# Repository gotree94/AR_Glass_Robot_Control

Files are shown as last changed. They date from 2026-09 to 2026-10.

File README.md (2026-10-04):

# AR 안경 기반 협동로봇 Teleop/VLA 프로젝트

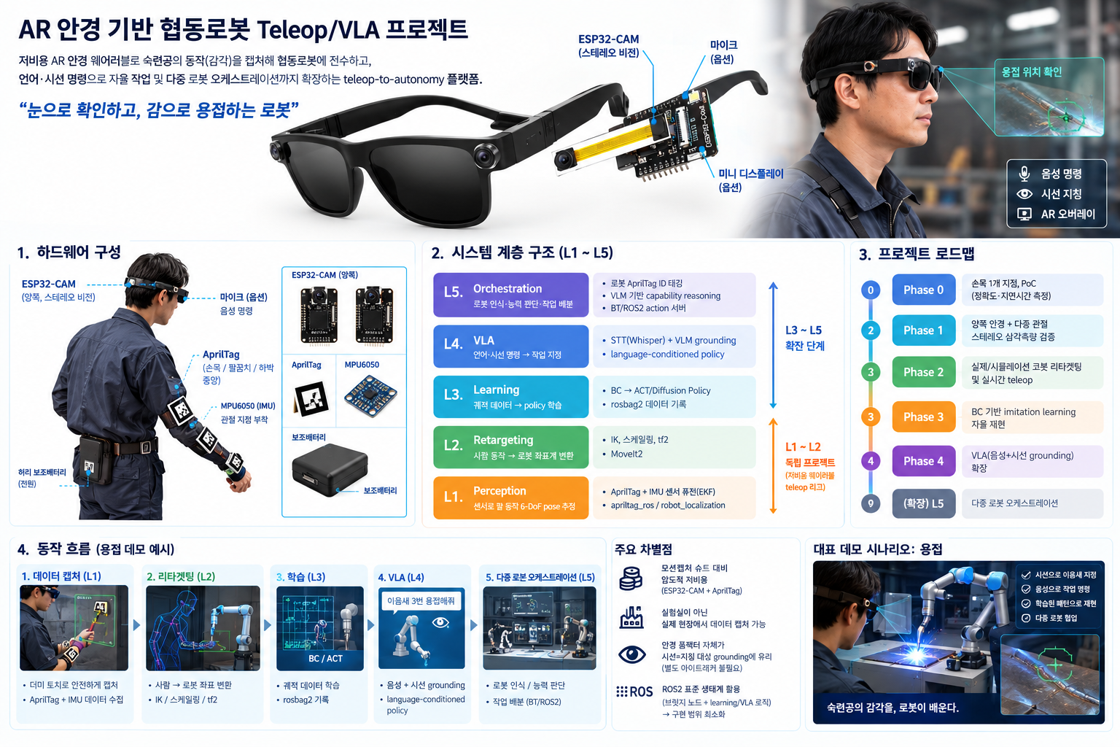
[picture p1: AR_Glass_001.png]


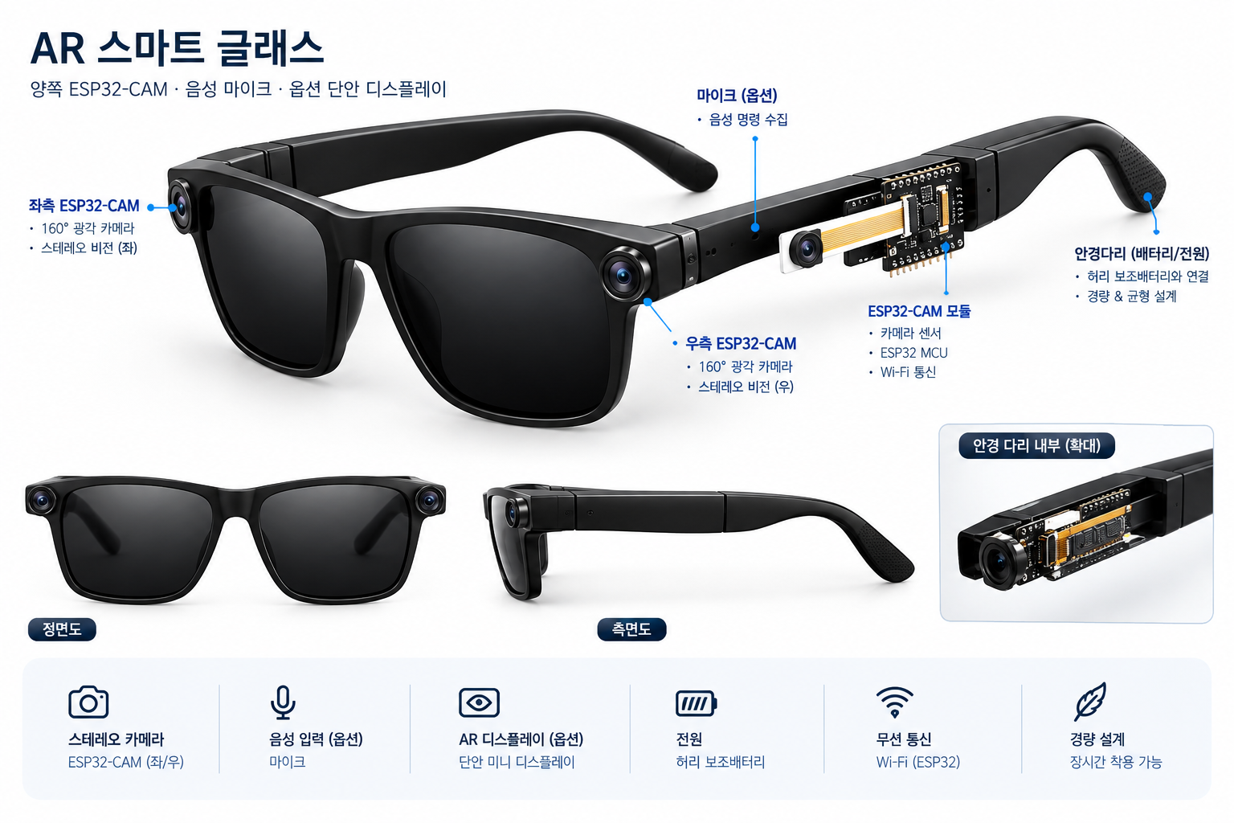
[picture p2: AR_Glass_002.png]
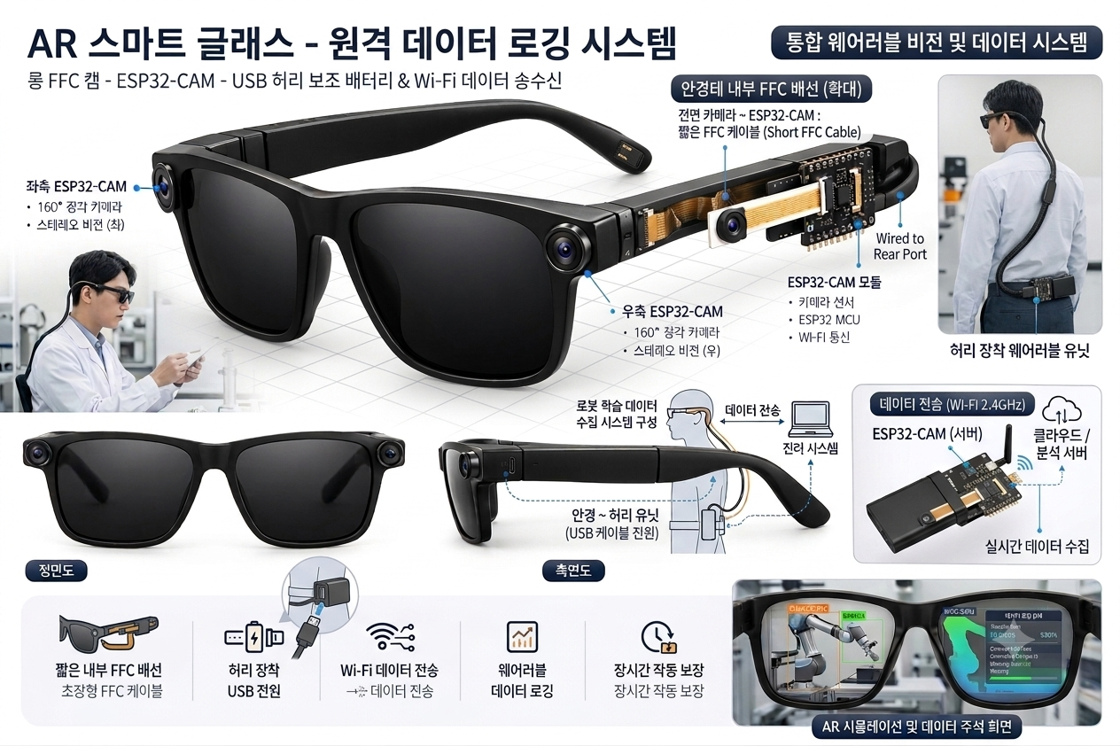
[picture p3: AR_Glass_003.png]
 

---

## 한 줄 컨셉
- 저비용 AR 안경 웨어러블로 숙련공의 동작(감각)을 캡처해 협동로봇에 전수하고,
- 언어·시선 명령으로 자율 작업 및 다중 로봇 오케스트레이션까지 확장하는 teleop-to-autonomy 플랫폼.

## 태그라인
- "눈으로 확인하고, 감으로 용접하는 로봇"

## 하드웨어 구성
- 안경 양쪽 ESP32-CAM (스테레오 비전) + 허리 보조배터리 전원
- 손목 / 팔꿈치(또는 하박 중앙)에 AprilTag 부착
- 관절 지점에 MPU6050(IMU) 추가 → 비전-IMU 센서 퓨전으로 occlusion 보완, 샘플링레이트 향상
- (확장) 안경 마이크 → 음성 명령, (확장) 단안 미니 디스플레이 → AR 오버레이

---
## 1. Tag Glove (70mm * 70mm)

### Version 0.1

   * 제작시 한쪽이 부러지는 문제와, 착용성이 좋지 않음.

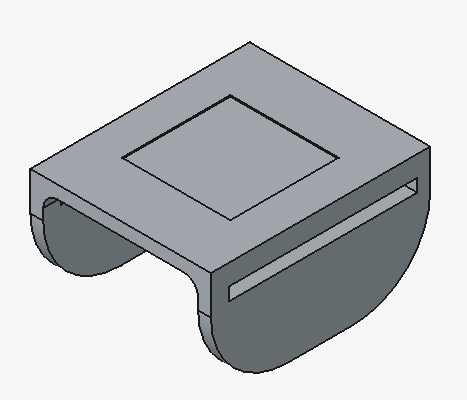
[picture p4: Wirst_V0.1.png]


### Version 0.2

   * 오른쪽과 왼쪽으로 분리 : 착용의 편의성 개선

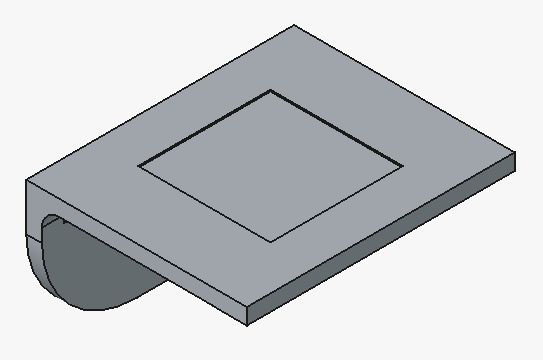
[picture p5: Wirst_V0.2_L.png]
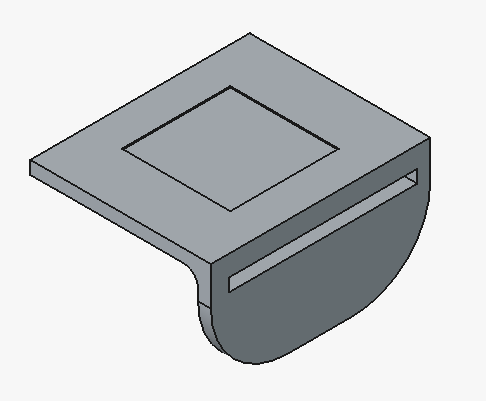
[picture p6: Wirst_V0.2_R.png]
 

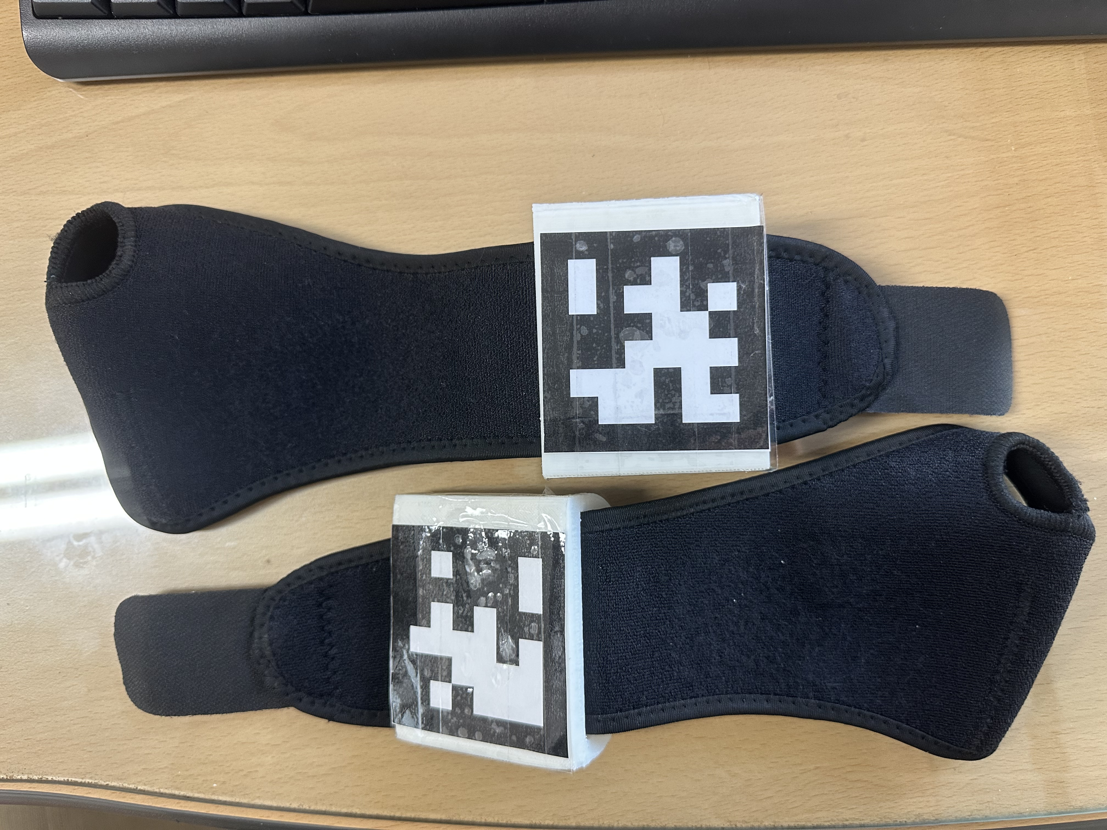
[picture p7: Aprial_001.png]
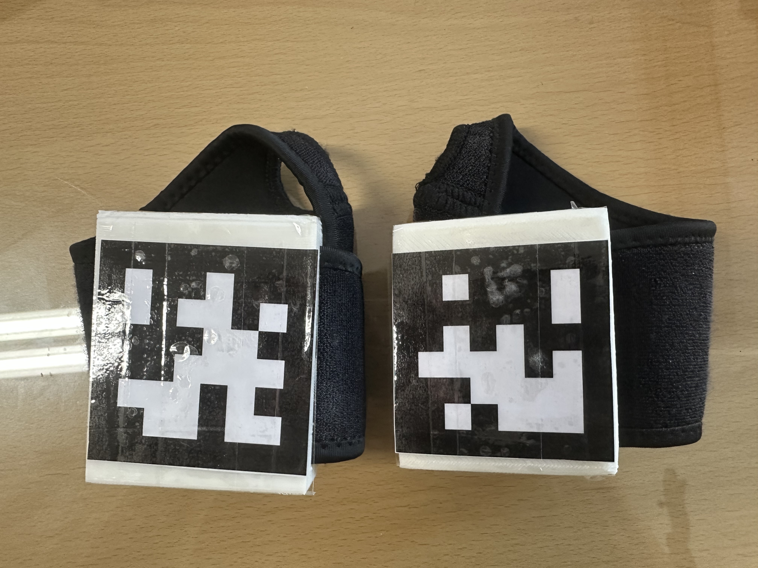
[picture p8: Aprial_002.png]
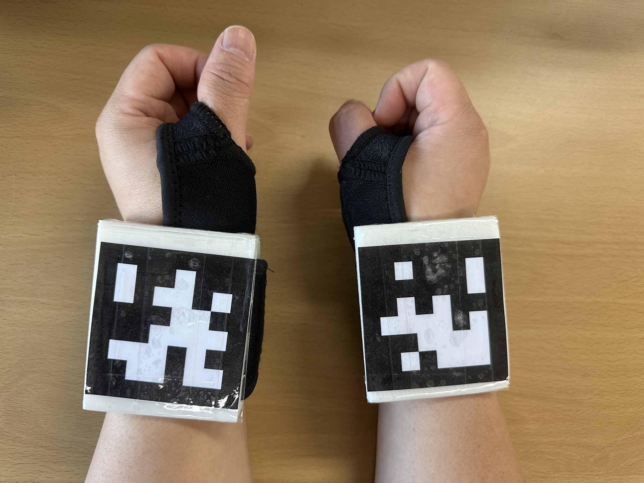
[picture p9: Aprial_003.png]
  

---

## 2. AR Glass

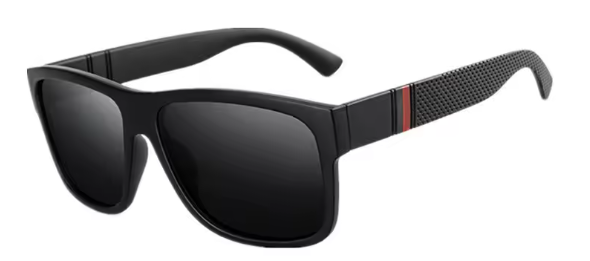
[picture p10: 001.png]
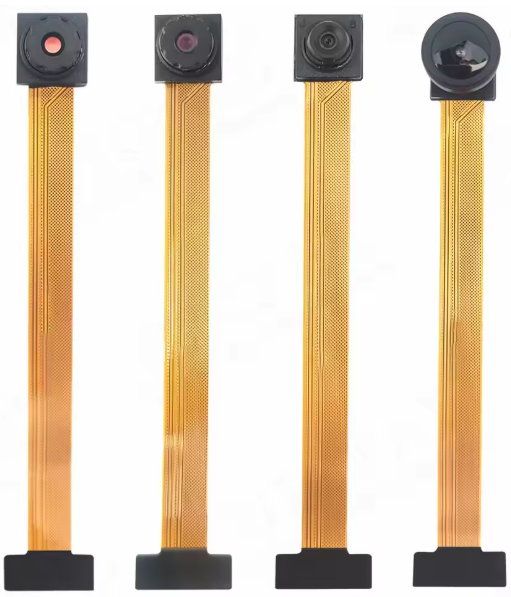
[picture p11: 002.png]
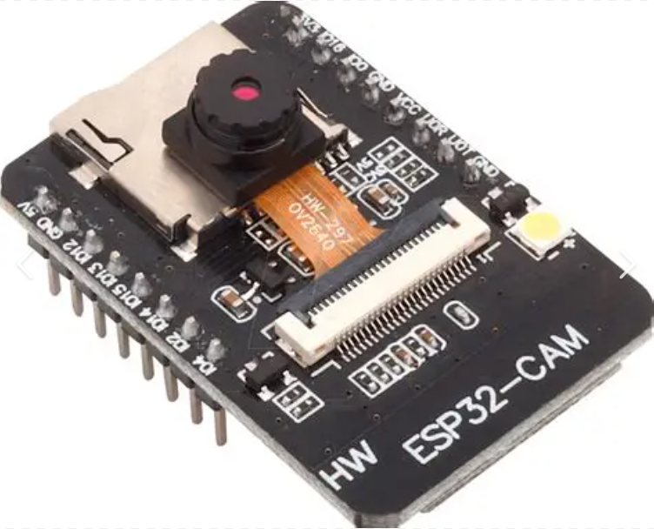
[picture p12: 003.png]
  

### 1. CAM Test

* 오른쪽 왼쪽 카메라 테스트

   * 교실 : http://192.168.0.137/ , http://192.168.0.69/
   * 연구실 : http://192.168.1.5/ , http://192.168.1.7/

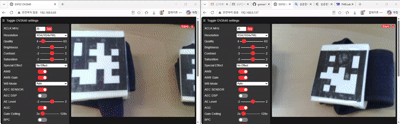
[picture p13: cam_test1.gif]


### 2. CAM Holder Design & Assemble.

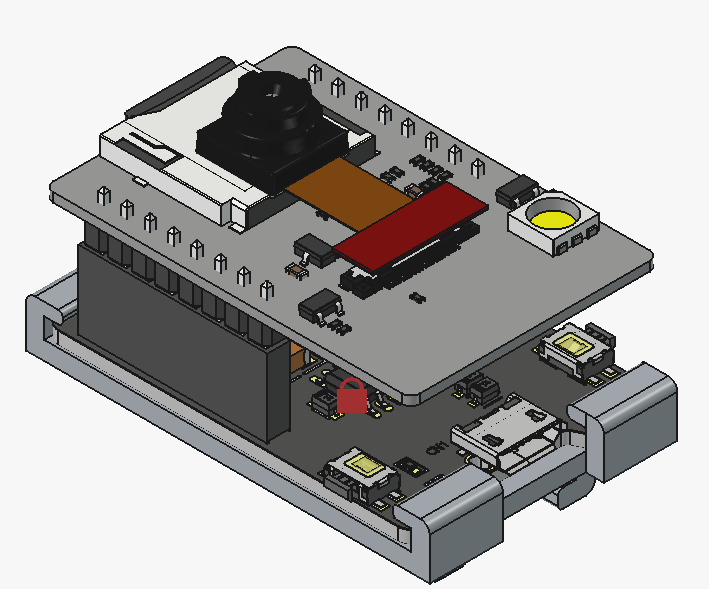
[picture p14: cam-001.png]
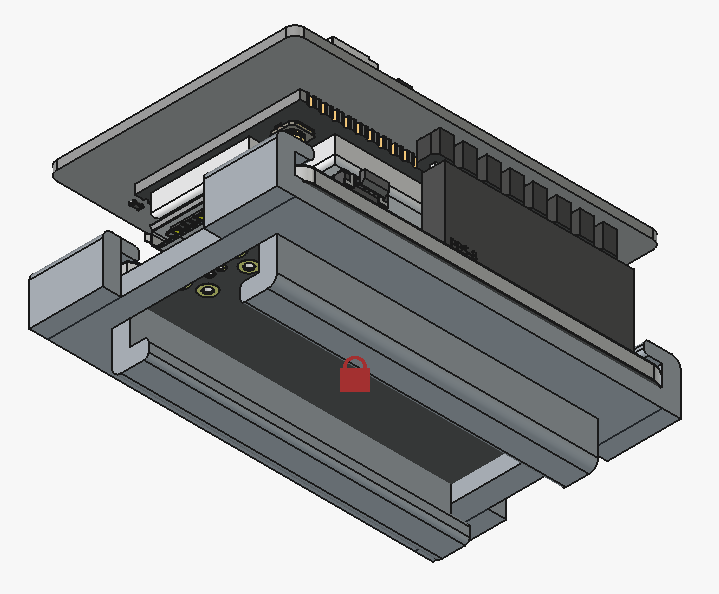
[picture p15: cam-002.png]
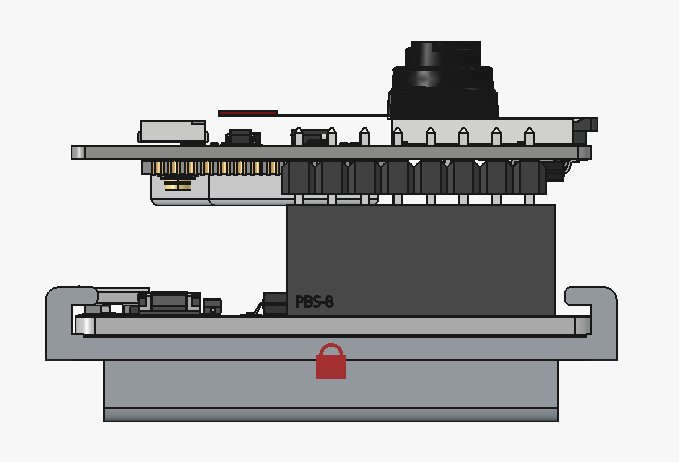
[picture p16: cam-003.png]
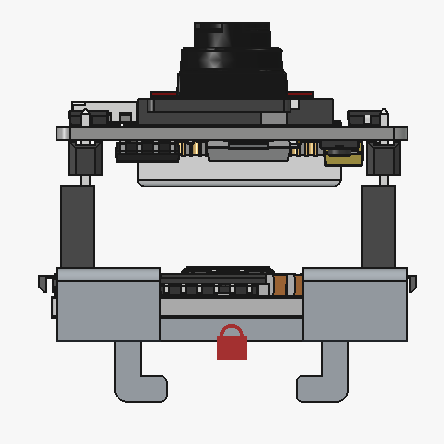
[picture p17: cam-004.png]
   

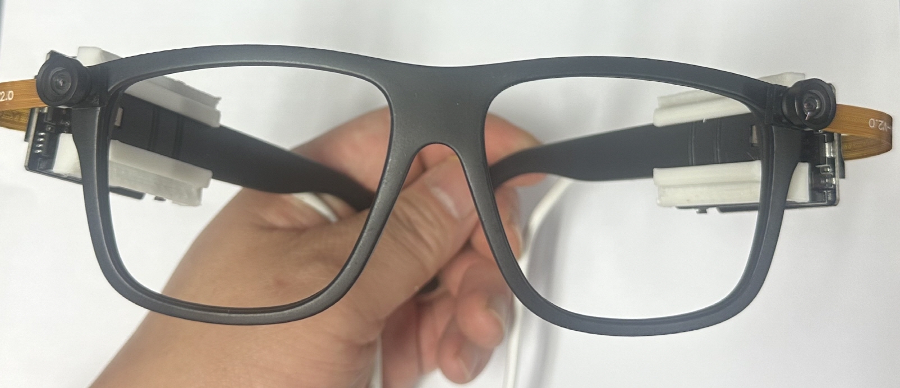
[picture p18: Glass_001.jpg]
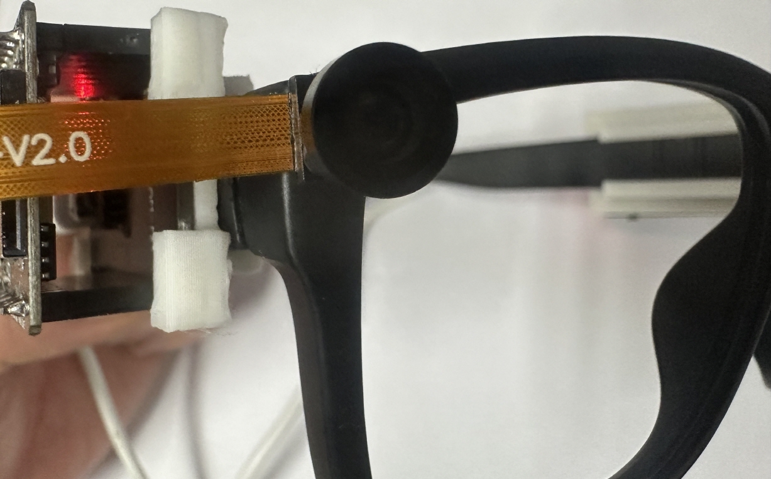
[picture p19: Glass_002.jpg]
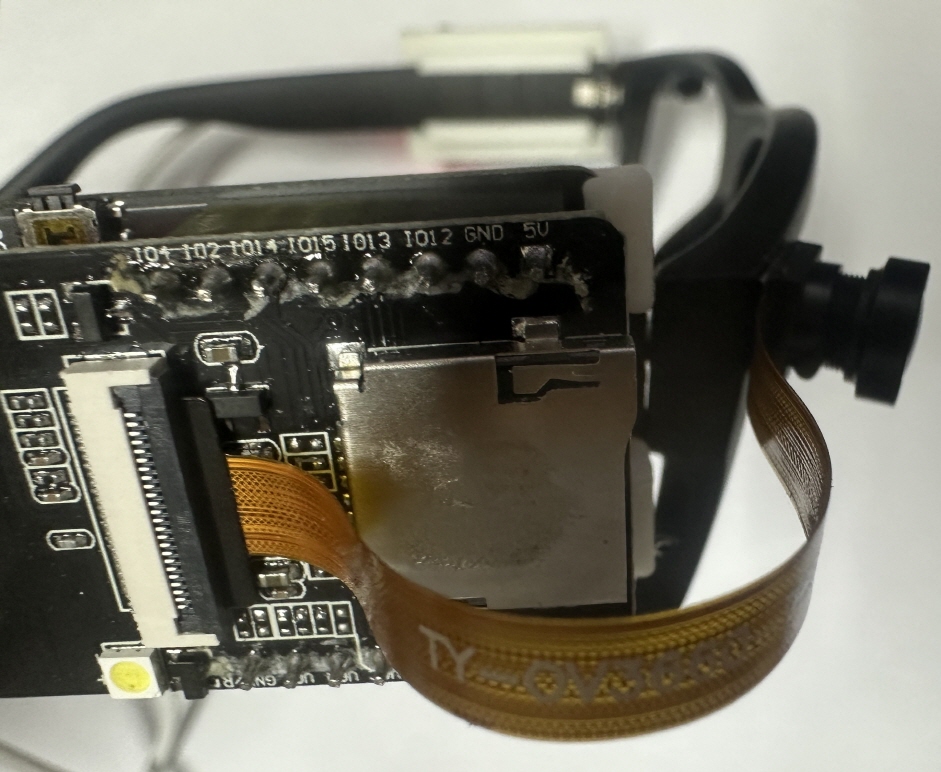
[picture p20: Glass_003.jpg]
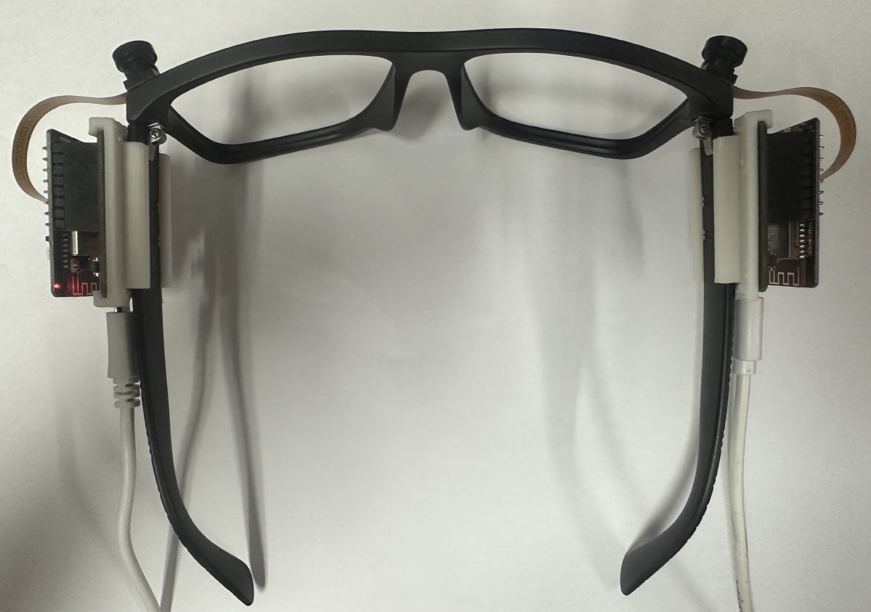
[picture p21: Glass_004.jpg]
   

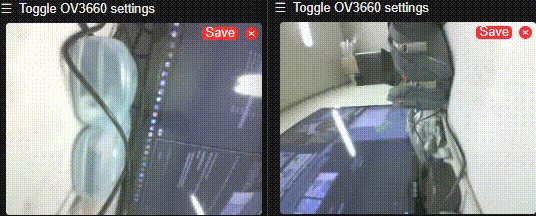
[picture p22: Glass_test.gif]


---

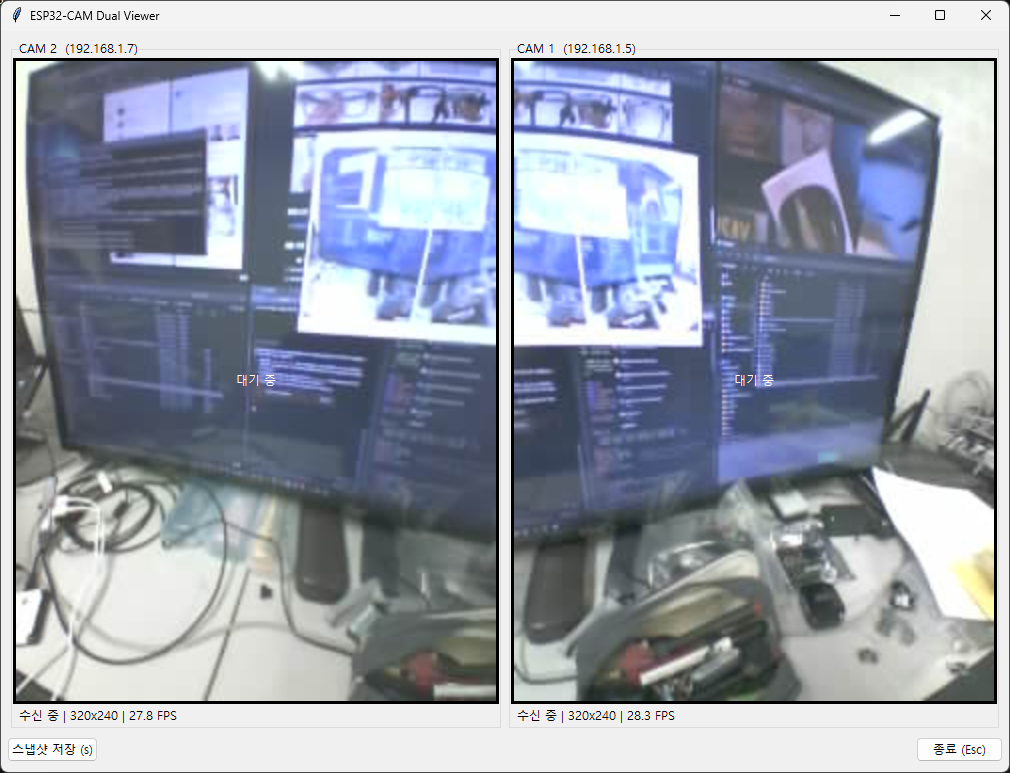
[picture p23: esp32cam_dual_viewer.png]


[esp32cam_dual_viewer.py](esp32cam_dual_viewer.py)

```python
#!/usr/bin/env python3
"""
ESP32-CAM 2대 MJPEG 스트림을 하나의 Tkinter UI에 표시

설치:  pip install requests pillow
실행:  python esp32cam_dual_viewer.py

- 스트림 주소: http://<IP>:81/stream  (CameraWebServer 기본)
- 카메라마다 별도 스레드로 수신, 끊기면 자동 재연결
- 's' 키 또는 [스냅샷 저장] 버튼: 현재 프레임을 snapshots/ 폴더에 저장
"""

import io
import os
import threading
import time
import tkinter as tk
from datetime import datetime
from tkinter import ttk

import requests
from PIL import Image, ImageTk

# ------------------------------------------------------------------ 설정
CAMERAS = [
    # rotate: 시계 방향이 +, 반시계 방향이 - (단위: 도, 90 단위만 지원)
    {"name": "CAM 2", "host": "192.168.1.7", "rotate": -90},   # 왼쪽
    {"name": "CAM 1", "host": "192.168.1.5", "rotate": 90},    # 오른쪽
]
STREAM_PORT = 81
STREAM_PATH = "/stream"
DISPLAY_SIZE = (480, 640)      # 카메라당 표시 영역 (가로, 세로) - 90도 회전하면 세로가 길어짐
UI_REFRESH_MS = 30             # UI 갱신 주기
STALE_SEC = 3.0                # 이 시간 동안 프레임 없으면 '끊김' 표시
SNAPSHOT_DIR = "snapshots"
# ----------------------------------------------------------------------

def rotate_img(img, deg):
    """시계 방향 +deg 회전 (PIL의 rotate는 반시계가 +이므로 부호 반전)"""
    deg %= 360
    if deg == 0:
        return img
    return img.rotate(-deg, expand=True)

def fit_to_box(img, size):
    """비율을 유지한 채 size 안에 맞추고 나머지는 검은색으로 채움"""
    scale = min(size[0] / img.width, size[1] / img.height)
    new_w, new_h = max(1, int(img.width * scale)), max(1, int(img.height * scale))
    img = img.resize((new_w, new_h), Image.BILINEAR)
    canvas = Image.new("RGB", size, "black")
    canvas.paste(img, ((size[0] - new_w) // 2, (size[1] - new_h) // 2))
    return canvas

class CamWorker(threading.Thread):
    """MJPEG 스트림을 받아 최신 프레임(PIL.Image)만 보관하는 스레드"""

    def __init__(self, name, host):
        super().__init__(daemon=True)
        self.name = name
        self.url = f"http://{host}:{STREAM_PORT}{STREAM_PATH}"
        self._stop_evt = threading.Event()
        self._lock = threading.Lock()
        self._frame = None
        self._frame_time = 0.0
        self._fps = 0.0
        self.status = "연결 중..."

    # ---- 외부에서 호출
    def get_frame(self):
        with self._lock:
            return self._frame, self._frame_time, self._fps

    def stop(self):
        self._stop_evt.set()

    # ---- 스레드 본체
    def run(self):
        while not self._stop_evt.is_set():
            try:
                self.status = "연결 중..."
                with requests.get(self.url, stream=True, timeout=(3, 5)) as resp:
                    resp.raise_for_status()
                    self.status = "수신 중"
                    self._read_mjpeg(resp)
            except Exception as e:  # 네트워크 오류 등
                self.status = f"오류: {type(e).__name__}"
            # 재연결 전 잠깐 대기
            self._stop_evt.wait(1.5)

    def _read_mjpeg(self, resp):
        buf = b""
        t0, n = time.time(), 0
        for chunk in resp.iter_content(chunk_size=1024):
            if self._stop_evt.is_set():
                return
            if not chunk:
                continue
            buf += chunk
            while True:
                soi = buf.find(b"\xff\xd8")          # JPEG 시작
                if soi == -1:
                    buf = buf[-1:]
                    break
                eoi = buf.find(b"\xff\xd9", soi + 2)  # JPEG 끝
                if eoi == -1:
                    buf = buf[soi:]
                    break
                jpg, buf = buf[soi:eoi + 2], buf[eoi + 2:]
                try:
                    img = Image.open(io.BytesIO(jpg))
                    img.load()
                except Exception:
                    continue  # 깨진 프레임은 버림
                n += 1
                now = time.time()
                with self._lock:
                    self._frame = img
                    self._frame_time = now
                    if now - t0 >= 1.0:
                        self._fps = n / (now - t0)
                        t0, n = now, 0

class App:
    def __init__(self, root):
        self.root = root
        root.title("ESP32-CAM Dual Viewer")
        root.protocol("WM_DELETE_WINDOW", self.on_close)
        root.bind("<Key-s>", lambda e: self.save_snapshots())
        root.bind("<Escape>", lambda e: self.on_close())

        self.workers = [CamWorker(c["name"], c["host"]) for c in CAMERAS]
        self.labels, self.info_vars, self.photos = [], [], [None] * len(CAMERAS)

        frame = ttk.Frame(root, padding=6)
        frame.pack(fill="both", expand=True)

        for i, c in enumerate(CAMERAS):
            box = ttk.LabelFrame(frame, text=f"{c['name']}  ({c['host']})")
            box.grid(row=0, column=i, padx=4, pady=4)
            lbl = tk.Label(box, width=DISPLAY_SIZE[0], height=DISPLAY_SIZE[1],
                           bg="black", fg="white", text="대기 중",
                           compound="center")
            # Label의 width/height는 이미지가 없을 때 '문자 단위'이므로 픽셀 지정용 빈 이미지 사용
            blank = ImageTk.PhotoImage(Image.new("RGB", DISPLAY_SIZE, "black"))
            lbl.configure(image=blank, width=DISPLAY_SIZE[0], height=DISPLAY_SIZE[1])
            lbl.image = blank
            lbl.pack()
            var = tk.StringVar(value="-")
            ttk.Label(box, textvariable=var).pack(anchor="w", padx=4, pady=2)
            self.labels.append(lbl)
            self.info_vars.append(var)

        bar = ttk.Frame(frame)
        bar.grid(row=1, column=0, columnspan=len(CAMERAS), sticky="ew", pady=4)
        ttk.Button(bar, text="스냅샷 저장 (s)", command=self.save_snapshots).pack(side="left")
        ttk.Button(bar, text="종료 (Esc)", command=self.on_close).pack(side="right")

        for w in self.workers:
            w.start()
        self.update_ui()

    def update_ui(self):
        now = time.time()
        for i, w in enumerate(self.workers):
            img, ts, fps = w.get_frame()
            alive = img is not None and (now - ts) < STALE_SEC
            if alive:
                rot = rotate_img(img.convert("RGB"), CAMERAS[i].get("rotate", 0))
                disp = fit_to_box(rot, DISPLAY_SIZE)
                self.photos[i] = ImageTk.PhotoImage(disp)
                self.labels[i].configure(image=self.photos[i])
                self.labels[i].image = self.photos[i]
                self.info_vars[i].set(f"{w.status} | {img.size[0]}x{img.size[1]} | {fps:.1f} FPS")
            else:
                self.info_vars[i].set(f"끊김 - {w.status}")
        self.root.after(UI_REFRESH_MS, self.update_ui)

    def save_snapshots(self):
        os.makedirs(SNAPSHOT_DIR, exist_ok=True)
        stamp = datetime.now().strftime("%Y%m%d_%H%M%S")
        for c, w in zip(CAMERAS, self.workers):
            img, _, _ = w.get_frame()
            if img is not None:
                path = os.path.join(SNAPSHOT_DIR, f"{c['name'].replace(' ', '')}_{stamp}.jpg")
                rotate_img(img.convert("RGB"), c.get("rotate", 0)).save(path, quality=95)
                print("saved:", path)

    def on_close(self):
        for w in self.workers:
            w.stop()
        self.root.destroy()

if __name__ == "__main__":
    root = tk.Tk()
    App(root)
    root.mainloop()
```

### AprilTag_6개 인식 확인



* ESP32-CAM Dual Viewer + AprilTag 인식
   * ESP32-CAM 2대의 MJPEG 스트림을 하나의 창에 표시하고, AprilTag(36h11, ID 0~5)를 인식해 거리와 위치를 보여줍니다.

#### 설치

```bash
pip install requests pillow numpy "opencv-python>=4.7"
```

#### 실행

```bash
python esp32cam_dual_viewer.py
```

#### 동작

- 회전을 적용한 화면에서 태그를 찾아 **녹색 테두리, 좌표축, `ID번호 거리mm`**를 화면에 그립니다.
- 각 카메라 화면 아래에 검출된 태그의 **이름, 거리, 카메라 기준 xyz(mm)**가 표시됩니다. 이름은 태그 이미지의 라벨을 그대로 사용합니다.
- 태그 크기는 **68mm**(검은 테두리 바깥 기준)로 `TAG_SIZE_MM`에 설정되어 있습니다.
- **ID 0~5 외의 태그는 오검출 방지를 위해 무시**합니다.
- 하단의 **"AprilTag 인식"** 체크박스로 인식을 켜고 끌 수 있습니다.
- 스냅샷(`s` 키)은 표시가 없는 깨끗한 프레임으로 `snapshots/`에 저장됩니다.
- 새 프레임이 들어올 때만 검출하므로 UI가 불필요하게 바쁘지 않습니다.

##### 태그 ID

| ID | 이름 | ID | 이름 |
|----|---|----|---|
| 0 | `RIGHT_1_THUMB_INDEX` | 3 | `LEFT_1_THUMB_INDEX` |
| 1 | `RIGHT_2_HAND` | 4 | `LEFT_2_HAND` |
| 2 | `RIGHT_3_FOREARM` | 5 | `LEFT_3_FOREARM` |

#### 거리 정확도 보정

- ESP32-CAM은 카메라 보정(캘리브레이션) 값이 없어서, 거리와 xyz는 `CAMERAS`의 **`fov`**(회전 전 원본 영상의 가로 화각, 기본 65°)로 추정한 값입니다.
- 태그를 카메라에서 정확히 **300mm** 떨어뜨려 놓고, 표시되는 거리가 그와 맞을 때까지 `fov`를 조정하세요.
  - 표시 거리가 실제보다 **크면** `fov`를 **키웁니다**.
  - 표시 거리가 실제보다 **작으면** `fov`를 **줄입니다**.
- 광각 렌즈 모듈은 화각이 100° 이상일 수 있습니다. 이 경우 렌즈 왜곡 때문에 화면 가장자리에서 오차가 커집니다.
- 정밀한 위치가 필요하면 체커보드로 카메라 보정을 해서 카메라 행렬과 왜곡 계수를 코드에 넣는 방식으로 확장할 수 있습니다.

#### 인식률을 높이는 팁

- 태그 주변에 **흰 여백**을 태그 한 칸(약 8mm) 이상 확보하세요.
- 해상도는 **VGA(640x480) 이상**이 좋습니다. QVGA에서는 인식 가능 거리가 크게 줄어듭니다.
- 화면에서 태그 한 변이 **약 30px 이상**이어야 인식되고, 안정적으로는 **50px 이상**이 좋습니다.

##### 인식 가능 거리 (68mm 태그, VGA, 화각 65° 기준)

| 태그 한 변(px) | 거리 |
|---|---|
| 114px | 약 30cm |
| 50px | 약 70cm |
| 30px | 약 110cm (인식 한계) |

화각이 넓은 렌즈일수록 같은 거리에서 태그가 작게 보이므로 인식 가능 거리는 짧아집니다.

#### 참고

- 스트림 주소는 `http://<IP>:81/stream`입니다. 브라우저에서 스트림을 켜 둔 상태면 연결되지 않으므로 탭을 닫아 주세요.
- 회전은 `CAMERAS`의 `rotate`(시계 방향 +, 반시계 방향 -, 90 단위)로 설정합니다.

```python
#!/usr/bin/env python3
"""
ESP32-CAM 2대 MJPEG 스트림을 하나의 Tkinter UI에 표시 + AprilTag(36h11) 인식

설치:  pip install requests pillow numpy "opencv-python>=4.7"
실행:  python esp32cam_dual_viewer.py

- 스트림 주소: http://<IP>:81/stream  (CameraWebServer 기본)
- 카메라마다 별도 스레드로 수신, 끊기면 자동 재연결
- AprilTag 36h11, ID 0~5, 실제 크기 68mm (검은 테두리 바깥쪽 기준)
- 's' 키 또는 [스냅샷 저장] 버튼: 회전 적용된 원본 프레임을 snapshots/ 에 저장
"""

import io
import math
import os
import threading
import time
import tkinter as tk
from datetime import datetime
from tkinter import ttk

import cv2
import numpy as np
import requests
from PIL import Image, ImageTk

# ------------------------------------------------------------------ 설정
CAMERAS = [
    # rotate: 시계 방향이 +, 반시계 방향이 - (단위: 도, 90 단위만 지원)
    # fov   : 회전 전 원본 영상의 '가로' 화각(도). 거리 계산용 추정값 (아래 설명 참고)
    {"name": "CAM 2", "host": "192.168.1.7", "rotate": -90, "fov": 65.0},   # 왼쪽
    {"name": "CAM 1", "host": "192.168.1.5", "rotate": 90,  "fov": 65.0},   # 오른쪽
]
STREAM_PORT = 81
STREAM_PATH = "/stream"
DISPLAY_SIZE = (480, 640)      # 카메라당 표시 영역 (가로, 세로)
UI_REFRESH_MS = 30             # UI 갱신 주기
STALE_SEC = 3.0                # 이 시간 동안 프레임 없으면 '끊김' 표시
SNAPSHOT_DIR = "snapshots"

# --- AprilTag 설정
TAG_DICT = cv2.aruco.DICT_APRILTAG_36h11
TAG_SIZE_MM = 68.0             # 검은 테두리 바깥 한 변의 실제 길이
TAG_NAMES = {
    0: "RIGHT_1_THUMB_INDEX",
    1: "RIGHT_2_HAND",
    2: "RIGHT_3_FOREARM",
    3: "LEFT_1_THUMB_INDEX",
    4: "LEFT_2_HAND",
    5: "LEFT_3_FOREARM",
}
# ----------------------------------------------------------------------

def rotate_img(img, deg):
    """시계 방향 +deg 회전 (PIL의 rotate는 반시계가 +이므로 부호 반전)"""
    deg %= 360
    if deg == 0:
        return img
    return img.rotate(-deg, expand=True)

def fit_to_box(img, size):
    """비율을 유지한 채 size 안에 맞추고 나머지는 검은색으로 채움"""
    scale = min(size[0] / img.width, size[1] / img.height)
    new_w, new_h = max(1, int(img.width * scale)), max(1, int(img.height * scale))
    img = img.resize((new_w, new_h), Image.BILINEAR)
    canvas = Image.new("RGB", size, "black")
    canvas.paste(img, ((size[0] - new_w) // 2, (size[1] - new_h) // 2))
    return canvas

class TagDetector:
    """AprilTag 36h11 검출 + 68mm 기준 자세(위치) 추정 + 화면 표시"""

    def __init__(self):
        dictionary = cv2.aruco.getPredefinedDictionary(TAG_DICT)
        params = cv2.aruco.DetectorParameters()
        params.cornerRefinementMethod = cv2.aruco.CORNER_REFINE_SUBPIX
        self.detector = cv2.aruco.ArucoDetector(dictionary, params)
        h = TAG_SIZE_MM / 2.0
        # 코너 순서: 좌상, 우상, 우하, 좌하 (태그 중심이 원점, 단위 mm)
        self.obj_pts = np.array([[-h, h, 0], [h, h, 0], [h, -h, 0], [-h, -h, 0]],
                                dtype=np.float64)

    def process(self, rgb, focal_px):
        """rgb(ndarray)에 검출 결과를 직접 그리고, 검출 리스트를 반환"""
        gray = cv2.cvtColor(rgb, cv2.COLOR_RGB2GRAY)
        corners, ids, _ = self.detector.detectMarkers(gray)
        results = []
        if ids is None:
            return results

        hgt, wid = gray.shape
        K = np.array([[focal_px, 0, wid / 2.0],
                      [0, focal_px, hgt / 2.0],
                      [0, 0, 1]], dtype=np.float64)
        dist = np.zeros(5)

        for c, tag_id in zip(corners, ids.flatten()):
            tag_id = int(tag_id)
            if tag_id not in TAG_NAMES:      # ID 0~5 외에는 무시
                continue
            pts = c.reshape(4, 2).astype(np.float64)
            ok, rvec, tvec = cv2.solvePnP(self.obj_pts, pts, K, dist,
                                          flags=cv2.SOLVEPNP_IPPE_SQUARE)
            if not ok:
                continue
            x, y, z = tvec.flatten()
            d = float(np.linalg.norm(tvec))
            results.append({"id": tag_id, "name": TAG_NAMES[tag_id],
                            "x": x, "y": y, "z": z, "dist": d})

            # ---- 그리기
            poly = pts.astype(np.int32).reshape(-1, 1, 2)
            cv2.polylines(rgb, [poly], True, (0, 255, 0), 2)
            cv2.circle(rgb, tuple(poly[0, 0]), 5, (255, 0, 0), -1)   # 좌상단 코너 표시
            cv2.drawFrameAxes(rgb, K, dist, rvec, tvec, TAG_SIZE_MM * 0.6, 2)
            label = f"ID{tag_id} {d:.0f}mm"
            org = (int(pts[:, 0].min()), max(15, int(pts[:, 1].min()) - 8))
            cv2.putText(rgb, label, org, cv2.FONT_HERSHEY_SIMPLEX, 0.55, (0, 0, 0), 3, cv2.LINE_AA)
            cv2.putText(rgb, label, org, cv2.FONT_HERSHEY_SIMPLEX, 0.55, (255, 255, 0), 1, cv2.LINE_AA)

        results.sort(key=lambda r: r["id"])
        return results

class CamWorker(threading.Thread):
    """MJPEG 스트림을 받아 최신 프레임(PIL.Image)만 보관하는 스레드"""

    def __init__(self, name, host):
        super().__init__(daemon=True)
        self.name = name
        self.url = f"http://{host}:{STREAM_PORT}{STREAM_PATH}"
        self._stop_evt = threading.Event()
        self._lock = threading.Lock()
        self._frame = None
        self._frame_time = 0.0
        self._fps = 0.0
        self.status = "연결 중..."

    # ---- 외부에서 호출
    def get_frame(self):
        with self._lock:
            return self._frame, self._frame_time, self._fps

    def stop(self):
        self._stop_evt.set()

    # ---- 스레드 본체
    def run(self):
        while not self._stop_evt.is_set():
            try:
                self.status = "연결 중..."
                with requests.get(self.url, stream=True, timeout=(3, 5)) as resp:
                    resp.raise_for_status()
                    self.status = "수신 중"
                    self._read_mjpeg(resp)
            except Exception as e:  # 네트워크 오류 등
                self.status = f"오류: {type(e).__name__}"
            # 재연결 전 잠깐 대기
            self._stop_evt.wait(1.5)

    def _read_mjpeg(self, resp):
        buf = b""
        t0, n = time.time(), 0
        for chunk in resp.iter_content(chunk_size=1024):
            if self._stop_evt.is_set():
                return
            if not chunk:
                continue
            buf += chunk
            while True:
                soi = buf.find(b"\xff\xd8")          # JPEG 시작
                if soi == -1:
                    buf = buf[-1:]
                    break
                eoi = buf.find(b"\xff\xd9", soi + 2)  # JPEG 끝
                if eoi == -1:
                    buf = buf[soi:]
                    break
                jpg, buf = buf[soi:eoi + 2], buf[eoi + 2:]
                try:
                    img = Image.open(io.BytesIO(jpg))
                    img.load()
                except Exception:
                    continue  # 깨진 프레임은 버림
                n += 1
                now = time.time()
                with self._lock:
                    self._frame = img
                    self._frame_time = now
                    if now - t0 >= 1.0:
                        self._fps = n / (now - t0)
                        t0, n = now, 0

class App:
    def __init__(self, root):
        self.root = root
        root.title("ESP32-CAM Dual Viewer + AprilTag")
        root.protocol("WM_DELETE_WINDOW", self.on_close)
        root.bind("<Key-s>", lambda e: self.save_snapshots())
        root.bind("<Escape>", lambda e: self.on_close())

        n = len(CAMERAS)
        self.detector = TagDetector()
        self.workers = [CamWorker(c["name"], c["host"]) for c in CAMERAS]
        self.labels, self.info_vars, self.tag_vars = [], [], []
        self.photos = [None] * n
        self.raw_rot = [None] * n      # 스냅샷용 (회전만 적용, 표시 없음)
        self.last_ts = [0.0] * n
        self.detect_on = tk.BooleanVar(value=True)

        frame = ttk.Frame(root, padding=6)
        frame.pack(fill="both", expand=True)

        for i, c in enumerate(CAMERAS):
            box = ttk.LabelFrame(frame, text=f"{c['name']}  ({c['host']})")
            box.grid(row=0, column=i, padx=4, pady=4)
            blank = ImageTk.PhotoImage(Image.new("RGB", DISPLAY_SIZE, "black"))
            lbl = tk.Label(box, image=blank, bg="black")
            lbl.image = blank
            lbl.pack()
            info = tk.StringVar(value="-")
            ttk.Label(box, textvariable=info).pack(anchor="w", padx=4, pady=(2, 0))
            tags = tk.StringVar(value="")
            tk.Label(box, textvariable=tags, font=("Consolas", 9), justify="left",
                     anchor="nw", height=6, width=62).pack(anchor="w", padx=4, pady=(0, 2))
            self.labels.append(lbl)
            self.info_vars.append(info)
            self.tag_vars.append(tags)

        bar = ttk.Frame(frame)
        bar.grid(row=1, column=0, columnspan=n, sticky="ew", pady=4)
        ttk.Button(bar, text="스냅샷 저장 (s)", command=self.save_snapshots).pack(side="left")
        ttk.Checkbutton(bar, text="AprilTag 인식", variable=self.detect_on).pack(side="left", padx=12)
        ttk.Button(bar, text="종료 (Esc)", command=self.on_close).pack(side="right")

        for w in self.workers:
            w.start()
        self.update_ui()

    def process_frame(self, i, img):
        """새 프레임 1장 처리: 회전 -> 태그 인식 -> 표시용 이미지 반환"""
        cam = CAMERAS[i]
        fov = cam.get("fov", 65.0)
        # 초점거리(px): 원본 가로 화각 기준. 회전해도 초점거리는 변하지 않음
        focal = (img.width / 2.0) / math.tan(math.radians(fov) / 2.0)

        raw = rotate_img(img.convert("RGB"), cam.get("rotate", 0))
        self.raw_rot[i] = raw
        arr = np.array(raw)                       # 복사본 (여기에만 그림)
        tags = self.detector.process(arr, focal) if self.detect_on.get() else []

        lines = [f"ID{t['id']} {t['name']:<19} {t['dist']:6.0f}mm  "
                 f"xyz=({t['x']:.0f},{t['y']:.0f},{t['z']:.0f})" for t in tags]
        self.tag_vars[i].set("\n".join(lines))
        return fit_to_box(Image.fromarray(arr), DISPLAY_SIZE), len(tags)

    def update_ui(self):
        now = time.time()
        for i, w in enumerate(self.workers):
            img, ts, fps = w.get_frame()
            alive = img is not None and (now - ts) < STALE_SEC
            if not alive:
                self.info_vars[i].set(f"끊김 - {w.status}")
                self.tag_vars[i].set("")
                continue
            if ts != self.last_ts[i]:             # 새 프레임일 때만 처리
                self.last_ts[i] = ts
                disp, n_tags = self.process_frame(i, img)
                self.photos[i] = ImageTk.PhotoImage(disp)
                self.labels[i].configure(image=self.photos[i])
                self.labels[i].image = self.photos[i]
                self.info_vars[i].set(
                    f"{w.status} | {img.size[0]}x{img.size[1]} | {fps:.1f} FPS | 태그 {n_tags}개")
        self.root.after(UI_REFRESH_MS, self.update_ui)

    def save_snapshots(self):
        os.makedirs(SNAPSHOT_DIR, exist_ok=True)
        stamp = datetime.now().strftime("%Y%m%d_%H%M%S")
        for c, raw in zip(CAMERAS, self.raw_rot):
            if raw is not None:
                path = os.path.join(SNAPSHOT_DIR, f"{c['name'].replace(' ', '')}_{stamp}.jpg")
                raw.save(path, quality=95)
                print("saved:", path)

    def on_close(self):
        for w in self.workers:
            w.stop()
        self.root.destroy()

if __name__ == "__main__":
    root = tk.Tk()
    App(root)
    root.mainloop()
```

---
## 투명 LCD 
- [유튜브링크](https://www.youtube.com/results?search_query=%ED%88%AC%EB%AA%85LCD+%EC%9E%90%EC%9E%91)

---

## 계층 구조 (L1~L5)

| 계층 | 역할 | 핵심 기술 |
|---|---|---|
| L1. Perception | 센서로 팔 동작 6-DoF pose 추정 | AprilTag + IMU 센서 퓨전(EKF), ROS2 `apriltag_ros`/`robot_localization` |
| L2. Retargeting | 사람 동작 → 로봇 좌표계 변환 | IK, 스케일링, `tf2`, `MoveIt2` |
| L3. Learning | 궤적 데이터 → policy 학습 | BC → ACT/Diffusion Policy, `rosbag2` 데이터 기록 |
| L4. VLA | 언어·시선 명령 → 작업 지정 | STT(Whisper) + VLM grounding, language-conditioned policy |
| L5. Orchestration | 로봇 인식·능력 판단·작업 배분 | 로봇 AprilTag ID 태깅, VLM 기반 capability reasoning, BT/ROS2 action 서버 |

L1 ~ L2만으로도 독립적인 프로젝트(저비용 웨어러블 teleop 리그)가 성립하며, L3 ~ L5는 순차적 확장.

## 로드맵
- Phase 0: 손목 1개 지점, PoC(정확도·지연시간 측정)
- Phase 1: 양쪽 안경 + 다중 관절, 스테레오 삼각측량 검증
- Phase 2: 실제/시뮬레이션 코봇 리타겟팅 및 실시간 teleop
- Phase 3: BC 기반 imitation learning, 자율 재현
- Phase 4: VLA(음성+시선 grounding) 확장
- (확장) L5 다중 로봇 오케스트레이션

## 핵심 차별점
- 모션캡처 슈트 대비 압도적 저비용(ESP32-CAM+AprilTag)
- 실험실이 아닌 실제 현장에서 데이터 캡처 가능
- 안경 폼팩터 자체가 시선=지칭 대상 grounding에 유리 (별도 아이트래커 불필요)
- ROS2 표준 생태계(apriltag_ros, robot_localization, MoveIt2, rosbag2, 코봇 공식 드라이버) 활용으로 직접 구현 범위를 브릿지 노드 + learning/VLA 로직으로 최소화

## "감을 느끼는 로봇" 컨셉
- 용접처럼 작업 중 시야가 가려지는(불꽃, 스패터) 환경을 전제로 설계
- 학습은 불꽃 없는 안전한 상태(더미 토치 리허설)에서 다양한 조건(이음새 각도, 틈새 폭)별로 반복 시연 → 조건-대응 패턴을 학습(단순 궤적 암기가 아님)
- 실전에서는 "확인(눈)": 작업 직전 비전으로 조건 인식 → "실행(감)": 학습된 policy가 조건에 맞춰 속도/각도/위빙을 스스로 미세조정해 수행
- 즉 암묵지(tacit knowledge)를 규칙이 아닌 학습으로 구현한다는 것이 기술적 본질이며, 로봇러닝의 generalization과 정확히 일치

## 사업화 시나리오 후보 (우선순위 순)

1. **숙련공 동작 전수 서비스** — 고령화·인력난 산업(용접·조립 등)에서 티칭 시간 단축. 로봇 판매가 아닌 티칭 서비스/솔루션. 27년 정밀 장비 이력과 직결
2. **원격 전문가 파견 대체** — 특수 장비(반도체/의료기기/방산) 정비 출장을 원격 시연-재현으로 대체. HoloLens 원류 스토리와 가장 가까움
3. **다품종 소량생산 즉석 재배치** — 중소 제조업 대상 노코드 로봇 재교육 솔루션. 시장은 넓으나 기존 코봇 티칭 업체와 경쟁
4. **교육기관 숙련도 전수 플랫폼** — 기존 강사/커리큘럼 사업과 직결, 리스크 낮으나 시장 규모 상대적으로 작음

## 대표 데모 시나리오: 용접

- 문제: 용접은 토치 각도·속도·위빙 패턴이 숙련공의 감각 영역이라 매뉴얼화·티칭이 어렵고, 인력난이 특히 심각(뿌리산업)
- 흐름: 더미 토치로 안전하게 캡처(L1) → 조건별 궤적/속도 리타겟팅(L2, 시간축 정밀도 중요) → BC/ACT로 학습(L3) → 음성+시선으로 이음새 지정, seam tracking으로 재확인(L4) → 다중 로봇 배분(L5)
- 표적 고객: 조선, 자동차 부품, 철골 구조물 등 다품종 소량 용접을 하는 중소 뿌리산업 업체
- 초기 포지셔닝: 완전 자율 용접이 아닌 "티칭 보조 툴"(기존 SI업체·로봇업체에 보완재로 제시)
- 리스크: 실제 아크 환경에서 ESP32-CAM/AprilTag 신뢰성 미검증(더미 토치 리허설로 시작), 용접 품질은 궤적만으로 완전 보장 안 됨(전류·속도·와이어 송급 데이터는 장기 과제)

## 다음으로 채울 것
- 구체적 킬러 데모 태스크 1개 확정 (예: 특정 이음새 용접 재현)
- Phase 0 MVP의 BOM·배선·실험 계획 구체화
- 실패 조건과 플랜 B 정의 (스테레오 정확도 부족 시, occlusion 과다 시 등)

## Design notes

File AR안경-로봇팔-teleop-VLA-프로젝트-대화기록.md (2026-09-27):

# AR 안경 + 로봇팔 Teleoperation / VLA 프로젝트 — 대화 기록

## 1. 최초 아이디어

안경 양쪽에 ESP32-CAM을 달고 전원은 허리춤에 보조배터리를 차서 운용.
손목, 손가락, 팔꿈치(또는 안 보이는 팔의 하박 중앙쯤)에 AprilTag를 부착하고,
ESP32-CAM을 통해 팔의 움직임을 인식하여 이를 로봇팔과 연동해 학습하는 시스템을 구축할 수 있을까?

**정리된 구조**

- 센싱 레이어: 안경 양쪽 ESP32-CAM → 스테레오 비전으로 깊이 추정. 전원은 허리 보조배터리 → USB-C 부스트 컨버터로 5V 공급, 케이블은 어깨선 따라 배선
- 마커 배치: 손목/팔꿈치(또는 하박 중앙) 중심으로 시작 권장. 손가락 단위는 해상도/거리상 인식률 저하 우려
- 처리 파이프라인: ESP32-CAM은 연산력이 약해 프레임을 Wi-Fi로 스트리밍해 별도 컴퓨트(라즈베리파이/PC/DGX Spark 등)에서 apriltag 라이브러리로 검출·pose 추정. 두 카메라의 태그 pose를 삼각측량하면 3D 위치/자세(6-DoF) 산출 가능
- 로봇팔 연동 및 학습: 6-DoF 시퀀스를 로봇팔 조인트 공간으로 IK 변환 → teleoperation 데모 수집 → imitation learning(behavior cloning) 또는 RL fine-tuning 파이프라인 구축
- 난이도 포인트: ESP32-CAM 프레임레이트/해상도-Wi-Fi 대역폭 트레이드오프, 안경 시야각에서의 occlusion 문제, 캘리브레이션(양안 간 거리, 렌즈 왜곡) 정밀도

VT6-mini와는 연동하지 않을 계획.

## 2. MPU6050(IMU) 추가 시 확장 범위

- Occlusion 구간 보완(센서 퓨전): 카메라 시야에서 태그가 가려지는 순간 IMU 적분으로 자세 추정 이어감. Kalman Filter / Complementary Filter로 비전(절대 위치, 저주파)+IMU(고주파 자세 변화) 퓨전
- 샘플링 레이트 향상: ESP32-CAM은 10~30fps 수준이지만 MPU6050은 I2C로 수백 Hz~1kHz까지 가능 → 빠른 동작 디테일 보강
- 관절별 배치 확장: 각 부착 지점마다 소형 MPU6050 부착 시 링크별 IK 정밀도 향상. 배선/전원 문제로 I2C 멀티드롭 또는 각 노드에 소형 MCU(ESP32-C3)+BLE/ESP-NOW 무선 전송 구조 고려
- 절대 방향(heading) 문제: MPU6050은 지자기 센서가 없어 yaw 드리프트 발생 → AprilTag의 절대 pose로 주기적 보정 필수. 필요시 MPU9250/ICM-20948 9축 IMU 업그레이드 고려
- 학습 데이터 품질 향상: 비전만으로 노이즈 큰 구간(빠른 동작, 순간적 가림)을 IMU가 메워 imitation learning용 궤적 데이터의 매끄러움/시간 해상도 개선

정리: MPU6050은 "위치"보다는 "자세 변화의 시간 해상도와 연속성"을 보강. 태그(절대 pose, 저속·정확) + IMU(상대 자세, 고속·드리프트 있음) 센서 퓨전 구조.

## 3. 최종 타겟: 협업 로봇 / 로봇 학습

이 웨어러블 시스템의 위치는 **저비용 teleoperation 데모 수집 장치** (ALOHA, Mobile ALOHA, UMI 등의 흐름과 유사).

- 데이터 수집 파이프라인이 핵심: (사람 동작 → 로봇 궤적) 쌍 데이터의 양과 질이 승부처
- 리타겟팅: 코봇 종류(UR, Doosan, Rainbow 등)에 따라 IK 솔버 필요. 사람 팔과 로봇팔의 링크 길이·가동범위 차이로 스케일링 + 조인트 리밋 매핑 필요
- 학습 알고리즘 방향:
  - 초기: Behavior Cloning(BC)
  - 발전: Diffusion Policy / ACT(Action Chunking Transformer)
  - 장기: BC로 초기화 후 RL fine-tuning(sim-to-real 또는 real-world RL)
- 시뮬레이션 우선 검증: MuJoCo/Isaac Sim/PyBullet에서 가상 로봇팔로 먼저 리타겟팅 검증. DGX Spark 환경 활용 가능
- 데이터 표준화: 공개 데이터셋(RT-X, Open X-Embodiment 등)과 포맷을 맞춰두면 확장성/사전학습 모델 활용에 유리

## 4. VLA(Vision-Language-Action) 확장

"공구 줘", "이 부분 잡아줘" 같은 음성/언어 명령으로 로봇이 액션을 취하는 것.

- 왜 유리한가: 지금 쌓는 (비전+IMU → 6-DoF pose → 로봇 궤적) 데이터에 음성/텍스트 명령만 페어링하면 (Vision, Language, Action) 삼중 데이터셋이 됨
- 추가 요소:
  - 음성 인식: 안경에 마이크 추가 → Whisper(로컬, DGX Spark 등) STT
  - 명령-액션 정렬: "이 부분 잡아줘" 같은 지시어는 화자가 보고 있는 대상(시선/카메라 프레임)과 연결되어야 함 → 안경 카메라의 시선 중심 프레임을 VLM에 넣어 grounding
  - VLA 모델 후보: OpenVLA, RT-2류, π0/Octo 계열 등 오픈소스 베이스를 자신의 코봇+데이터로 파인튜닝
- "공구 줘"(물체 지칭, fetch) vs "이 부분 잡아줘"(지시대명사, 공간 지칭)의 난이도 차이: 후자는 화자의 시선/손가락 포인팅 + 발화 시점 동기화 필요
- 단계적 접근:
  1) teleop 데이터 수집으로 BC policy 먼저 완성(언어 없이)
  2) 명령어 라벨 붙여 language-conditioned BC로 확장
  3) 시선 추적 + VLM grounding으로 open-vocabulary 지시("이거", "저거")까지 확장
- 핵심 포인트: 안경 기반 웨어러블 폼팩터가 "사람이 지금 어디를 보고 무엇을 말하는지"를 동시에 잡을 수 있어 일반 고정 카메라 로봇 셋업보다 지시대명사 기반 명령에 유리. 시선 추적을 나중에 추가할 걸 염두에 두고 안경 프레임 설계 시 카메라를 눈 축에 최대한 가깝게 배치하면 유리.

## 5. 프로젝트 빌드업: 계층 구조화

기능 나열형이라 조잡해 보일 수 있다는 우려에 대해, 계층을 분리하고 단계별 마일스톤으로 재구성.

### 계층 구조 (L1~L4)

| 계층 | 역할 | 핵심 기술 |
|---|---|---|
| L1. Perception | 안경 스테레오 ESP32-CAM + AprilTag + MPU6050 | 센서 퓨전(EKF), 6-DoF pose 추정 |
| L2. Retargeting | 사람 팔 동작 → 로봇팔 좌표계 변환 | IK, 스케일링, 조인트 리밋 매핑 |
| L3. Learning | 궤적 데이터 → policy | BC → ACT/Diffusion Policy |
| L4. Grounding (VLA) | 언어/시선 → "무엇을, 어디를" 지정 | STT + VLM grounding + language-conditioned policy |

L1~L2만으로도 완결된 프로젝트(저비용 웨어러블 teleop 리그)가 되고, L3, L4는 확장 단계.

### 단계별 로드맵

- **Phase 0 — 증명(PoC)**: 손목 1개 지점만, ESP32-CAM 1대 + AprilTag + MPU6050. pose 추정 정확도/지연시간 측정, 센서 퓨전 필터 튜닝
- **Phase 1 — 완전한 팔 캡처**: 안경 양쪽 + 손목/팔꿈치 확장, 스테레오 삼각측량 검증. occlusion 포함 끊김 없는 6-DoF 시퀀스 기록
- **Phase 2 — 리타겟팅 & Teleop**: 실제(또는 시뮬레이션) 코봇 매핑, 실시간 teleop 데모
- **Phase 3 — Imitation Learning**: 수집된 데모로 BC policy 학습, 반복 작업 자율 수행
- **Phase 4 — VLA 확장**: 음성 명령 + 시선/지칭 grounding 추가

### 프로젝트 정체성

"저비용 안경형 웨어러블로 산업 현장 숙련공의 동작을 그대로 코봇에 이식하는 teleop-to-autonomy 플랫폼" — 교육 커리큘럼(instructor 배경)과 연결 가능, Multimix의 기존 도메인(바이오 장비, 방산 UAS 등)과 결합 지점 모색 가능.

### 차별점

- 초저가: ESP32-CAM + AprilTag 조합은 모션캡처 슈트/스튜디오 대비 압도적으로 저렴
- 현장 배치 가능: 실험실이 아닌 실제 작업 현장에서 데이터 캡처 가능
- 시선 기반 VLA grounding: 안경 폼팩터로 별도 아이트래커 없이도 "화자가 보는 곳 = 지칭 대상" 근사 가능

## 6. ROS2 반영

ROS2는 프로젝트 전체를 관통하는 미들웨어/통합 레이어로 자연스럽게 결합.

- **L1. Perception**: ESP32-CAM 프레임, AprilTag pose, IMU 데이터를 ROS2 노드/토픽으로 publish. `apriltag_ros` 패키지 활용. IMU는 `sensor_msgs/Imu` 표준 메시지로 `robot_localization` 패키지(EKF/UKF)에 입력해 센서 퓨전 처리
- **L2. Retargeting**: `tf2`로 좌표계 관리(안경 프레임 → 손목 프레임 → 로봇 베이스 프레임). `MoveIt2`로 IK 솔버 + 충돌 회피
- **L3. Learning**: `rosbag2`로 (이미지, IMU, AprilTag pose, 로봇 조인트 상태)를 타임스탬프 동기화해서 기록. LeRobot 등 최근 로봇 학습 프레임워크도 ROS bag 포맷 지원
- **L4. VLA/언어**: STT 결과, VLM grounding 결과를 ROS2 토픽으로 publish, policy 노드가 구독. `action` 인터페이스(goal-feedback-result 구조)가 명령 상태 표현에 적합
- **실제 코봇 연동**: UR, Doosan 등 ROS2 공식 드라이버 제공(Universal_Robots_ROS2_Driver, doosan-robot2 등) 활용

ROS2 도입 시 직접 구현할 부분이 "ESP32-CAM/AprilTag/IMU를 ROS2 토픽으로 올리는 브릿지 노드"와 "learning/VLA 로직" 정도로 좁혀짐.

## 7. L5. Robot Discovery & Capability Reasoning (다중 로봇 오케스트레이션)

카메라로 로봇을 보고 인식해서, 이 로봇이 도와줄 수 있는지 다른 로봇을 호출해야 할지 판단하는 확장.

- **로봇 인식(Visual Robot Recognition)**: 카메라로 로봇 종류/그리퍼/가반하중 판별. 현실적으로는 로봇에도 AprilTag/QR로 ID 태깅 → 인식 즉시 사전 등록된 스펙(가반하중, 작업반경, 가용 여부) 조회
- **능력 매칭(Capability Reasoning)**: 물체 무게/크기(비전 추정 또는 DB) vs 로봇 스펙 비교. VLM을 활용해 "이 작업엔 이 로봇이 적합하다"는 자연어 추론 처리 — "LLM as robot orchestrator" 연구 흐름과 연결
- **다중 로봇 오케스트레이션**: ROS2에서 각 로봇을 독립 노드로 등록, BT(Behavior Tree, `BehaviorTree.CPP`/`py_trees`)나 ROS2 `action` 서버 구조로 "가용 로봇 목록 조회 → 적합 로봇 선택 → goal 전달". 여러 로봇 배치 시 네임스페이스 분리 + discovery 서비스
- **단계적 도입**: 로봇 1대 + 가능/불가능 판단(rule-based) → 2번째 로봇 추가해 hand-off 로직 → VLM 기반 자연어 추론으로 판단 근거 설명 가능하게

L4(VLA)와 결합 시 "공구 줘"라는 명령에 대해 시스템이 스스로 처리 가능 여부/다른 로봇 호출 여부까지 판단하는 **자율적 작업 배분 협업 로봇 오케스트레이션 시스템**으로 정체성 격상.

## 8. "와닿지 않는다"는 고민에 대한 정리

계층 구조는 탄탄하지만 부족하게 느껴지는 지점들:

1. **구체적인 킬러 데모 시나리오 부재**: "무엇이든 될 수 있는" 범용 플랫폼이라 손에 안 잡히는 상태. 하나의 구체적 태스크를 정하면 나머지 설계 결정이 좁혀짐
2. **"왜 나무님이어야 하는가"와의 결합 부재**: 27년 경력, 교육기관 강사, Multimix 창업자 배경과의 명시적 연결 필요. 예: "숙련공 노하우가 은퇴와 함께 사라지는 문제 → 웨어러블로 동작 캡처해 로봇에 전수 + 교육 자료 활용"
3. **첫 물리적 결과물 부재**: 모든 논의가 아키텍처 레벨. Phase 0(손목 1개, AprilTag+MPU6050, 정확도 측정)을 구체적 다음 액션으로 확정 필요
4. **실패 조건과 대안 부재**: 스테레오 정확도 부족, occlusion 과다 등의 리스크와 플랜 B 필요

## 9. HoloLens 원류 재조명

안경 아이디어는 예전 HoloLens류 AR을 떠올리며 나온 것. HoloLens는 원격지 정비를 시각적으로 도와주는 데 쓰였던 사례.

- **양방향 시스템으로의 확장 가능성**: 현재 구상은 "사람 동작 캡처 → 로봇 전달"(입력) 방향인데, "로봇이 학습한 동작을 다시 사람에게 AR로 오버레이"(출력)를 더하면 양방향이 됨. 예: 로봇이 학습한 최적 동작 경로를 안경 화면에 반투명 팔 궤적으로 표시해 숙련도 낮은 작업자 훈련용으로 활용
2. L5(로봇 인식/능력 판단) 결과를 로봇을 보는 순간 AR로 바로 오버레이하는 것이 HoloLens 활용법에 가까움
3. 현실적 제약: 광학 시스루 디스플레이(웨이브가이드 등)는 자체 제작 난이도가 매우 높음. 대안은 단안 OLED 미니 디스플레이로 "필요한 정보만 살짝 보여주는" 수준으로 스코프 축소

## 10. 차별화 기준: 타 교육기관 대비 "한 수 위"

- 타 교육기관 데모의 일반적 수준: 고정 카메라+YOLO+pick-and-place, 조이스틱/티칭펜던트 teleop 시연, ChatGPT API 연동한 단발성 LLM 명령 정도 (L1+L2 수준에서 끝남)
- 차별화는 신기술 발명이 아니라 "아무도 안 엮은 조합을 실제로 굴러가게 만든 것"에서 나옴
  1. 웨어러블 캡처라는 입력 방식 자체가 희귀함
  2. 원격 전문가 지원(HoloLens 원류)과의 결합 — 숙련자 원격 시연을 현장 로봇이 재현하는 스토리텔링
  3. L5 판단 계층 — 교육기관 데모에서 보기 드문(연구실 논문 단계) 수준

### 제안된 통합 내러티브

"숙련공 A가 안경을 쓰고 부품 조립 동작을 한 번 시연한다 → 그 동작이 실시간으로 원격지 로봇에 전달되어 로봇이 따라한다(teleop) → 몇 차례 반복 후 로봇이 스스로 그 작업을 학습해 자율 수행한다(BC) → 이후 작업자는 음성으로 "이거 잡아줘"만 말해도 로봇이 알아서 처리하고, 만약 이 로봇이 처리 못하는 작업이면 옆 로봇을 자동 호출한다(VLA+오케스트레이션)"

## 11. 사업화 시나리오 후보

**1. 숙련공 부족 산업의 "동작 전수" 서비스**
- 문제: 용접, 도장, 조립 등 숙련 기반 작업은 고령화로 인력난 심각, 매뉴얼화 어려워 로봇 티칭에 시간 오래 걸림
- 시나리오: 숙련공이 안경 쓰고 몇 번 작업 → 로봇이 동작 학습 → 티칭 시간 대폭 단축
- 사업 모델: 로봇 판매가 아닌 "티칭 서비스/솔루션". Multimix의 반도체/바이오 장비 도메인과 연결 가능

**2. 원격 전문가 파견 대체 (HoloLens 원류와 가장 가까움)**
- 문제: 특수 장비(반도체 장비, 의료기기, 방산 UAS) 정비는 전문가 직접 출장 필요, 비용·시간 큼
- 시나리오: 현장 로봇팔에 원격 전문가가 안경 기반으로 "시연"하면 그대로 재현 → 출장 없이 원격 정비/조립 지원
- 사업 모델: 장비 유지보수 계약에 "원격 로봇 지원" 옵션, 또는 정비 대행 서비스

**3. 다품종 소량생산 라인의 "즉석 재배치" 로봇**
- 문제: 중소 제조업 생산 품목 자주 변경, 재프로그래밍마다 SI업체 필요해 비용·시간 부담
- 시나리오: 작업자가 새 작업을 안경으로 몇 번 시연 → 당일 로봇 투입
- 사업 모델: 중소 제조업 대상 "노코드 로봇 재교육" 솔루션 — 시장 넓고 진입장벽 상대적으로 낮음

**4. 교육기관/기업 훈련용 "숙련도 전수 플랫폼"**
- 문제: 신입 기술자 훈련 시간 오래 걸리고, 숙련공 암묵지는 문서화 안 됨
- 시나리오: 숙련공 동작 캡처해 DB화 → 신입은 AR로 오버레이받아 훈련, 동시에 로봇도 학습
- 사업 모델: 기존 강사/커리큘럼 사업과 바로 결합 — 교육기관에 "로봇 교육 콘텐츠 + 실습 플랫폼"으로 판매

**우선순위 판단**: 1번(숙련공 전수), 2번(원격 전문가 대체)이 27년 이력(정밀 장비, 반도체, 의료기기)과 가장 직결되어 신뢰도를 얻기 쉬움. 3번은 시장은 넓지만 기존 코봇 티칭 솔루션 업체와 경쟁 필요. 4번은 리스크 가장 낮고 기존 사업과 바로 연결되지만 시장 규모 상대적으로 작음.

## 12. 용접 시나리오 구체화

### 시나리오: "숙련 용접공 동작 캡처 → 협동로봇 용접 전수 시스템"

**문제 정의**
- 용접은 매뉴얼화가 극히 어려운 작업(토치 각도, 이동 속도, 위빙 패턴, 아크 길이 유지가 숙련공의 감각)
- 기존 용접 로봇 티칭은 티칭펜던트로 포인트를 하나하나 찍는 방식 → 복잡한 비드일수록 반나절~며칠 소요
- 숙련 용접공은 고령화·구인난이 특히 심한 직종(뿌리산업 공통 문제)

**시스템 흐름 (L1~L5 매핑)**

- L1. 캡처: 숙련 용접공이 안경+손목/팔꿈치 AprilTag+IMU 착용, 실제(또는 더미 토치) 용접 작업 수행. 캡처 대상: 토치 팁 3D 궤적+자세(각도)+이동 속도 프로파일+위빙 패턴. 위빙 패턴(고주파 반복 동작)에 MPU6050의 높은 샘플링레이트가 유용
- L2. 리타겟팅: 사람 손목 pose → 실제 용접 로봇(협동로봇+토치 엔드이펙터) 조인트 궤적으로 IK 변환. 용접은 속도 프로파일이 품질에 직결(너무 빠르면 용입 부족, 느리면 과다 용착)되어 시간축 정보까지 정밀하게 리타겟팅해야 함
- L3. 학습: 여러 번의 시연(같은 이음새, 약간씩 다른 각도/자세)을 모아 BC 또는 ACT 계열로 학습. 비드 형상은 반복 가능한 패턴이 많아 imitation learning에 비교적 적합
- L4. VLA: "이 이음새 용접해줘" 음성 지시 + 시선으로 이음새 지정. 로봇이 비전으로 이음새(seam) 위치 재확인(seam tracking) 후 작업 개시 — 실제 용접 로봇 업계의 seam tracking 기능과 접점
- L5. 오케스트레이션: 여러 협동로봇 배치 라인에서 작업 난이도/로봇 스펙에 따라 자동 배분(소형 정밀 비드용 로봇 A, 대형 파워 용접용 로봇 B). 한 로봇 이상(용입 불량 감지) 발생 시 다른 로봇에 재할당

**사업화 포인트**
- 표적 고객: 조선, 자동차 부품, 철골 구조물 등 다품종 소량 용접이 많은 중소 뿌리산업 업체(대기업은 이미 대형 용접 자동화 라인 보유)
- 가치 제안: 숙련공 은퇴 전 동작을 데이터로 남기고, 신규 라인 티칭 시간을 대폭 단축
- 초기 진입 전략: 완전 자율 용접보다 "티칭 보조 툴"로 포지셔닝 — 기존 SI업체/용접 로봇 업체 입장에서 경쟁이 아닌 보완재로 받아들이기 쉬움

**현실적 리스크**
- 실제 용접 환경(아크광, 스패터, 열)에서 ESP32-CAM과 AprilTag가 버틸지는 별개 문제 → 개발 단계에서는 더미 토치로 리허설 캡처 방식이 안전하고 현실적
- 용접 품질(비드 형상, 용입 깊이)은 궤적만으로 100% 보장 안 됨 → 최종적으론 용접 파라미터(전류, 속도, 와이어 송급)까지 포함한 데이터 필요(장기 과제)

## 13. "감을 느끼는 로봇" 컨셉

용접 시 불꽃 때문에 카메라 시야가 가려지는 문제에서 나온 아이디어: 학습은 불꽃 없이 안경 낀 상태로, 실전 용접 시에는 용접 전에 확인만 하고 나머지는 "감으로" 수행.

**"감(感)"의 실제 기술적 의미**
- 숙련공이 "감으로 한다"는 것은, 명시적으로 설명은 못 하지만 미세한 조건 변화(모재 두께, 틈새, 자세 변화)에 따라 속도/각도/위빙을 무의식적으로 미세 조정하는 것
- 이는 imitation learning이 딥러닝으로 잡아내려는 것과 일치 — 암묵지(tacit knowledge)를 명시적 규칙 없이 패턴으로 학습
- "감을 느끼는 로봇"은 은유가 아니라 "규칙 기반이 아니라 학습 기반으로 미세조정하는 로봇"이라는 정확한 기술적 목표로 번역됨

**시나리오 재구성: "확인은 눈으로, 실행은 감으로"**

1. 학습 단계(불꽃 없이, 안전하게): 숙련공이 안경 끼고 더미 토치로 리허설 → 여러 조건(이음새 각도, 틈새 폭 다양하게)으로 반복 시연 → 로봇이 조건별 대응 패턴 학습(단일 궤적 암기가 아니라 조건-대응 매핑)
2. 실전 단계(용접 시):
   - 확인(눈): 작업 직전, 비전(카메라, AprilTag 또는 seam tracking)으로 이음새 형태/틈새를 명시적으로 인식
   - 실행(감): 인식 결과를 학습된 policy에 조건으로 입력 → 로봇이 학습된 감각대로 속도/각도/위빙을 스스로 미세조정해서 실행. 아크 불꽃이 시야를 가려도 문제없음(판단은 시작 전에 끝나고, 이후는 학습된 감각이 처리)
3. 기술적으로 "한 수 위"인 이유: 일반 용접 로봇은 정해진 궤적 정밀 재생(재현성은 높지만 조건 변화에 무력). 이 시스템은 조건을 보고 그에 맞는 감각적 대응을 스스로 선택 → 조건이 조금 달라져도 대응 가능(로봇러닝 분야의 "generalization"과 일치)

**태그라인 후보**: "눈으로 확인하고, 감으로 용접하는 로봇"

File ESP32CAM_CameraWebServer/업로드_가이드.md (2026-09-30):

# AR Glass — ESP32-CAM 펌웨어 업로드 가이드

두 눈 카메라(ESP32-CAM, AI-Thinker)에 **정식 `CameraWebServer` 펌웨어**를 넣는 방법입니다.

| 엔드포인트 | 역할 | 포트 | 상태 |
|---|---|---|---|
| `/stream` | MJPEG 스트림 (앱이 이걸 읽음) | **81** | 동작 |
| `/status` | 설정 JSON (`framesize/quality/...`) | **80** | 동작 |
| `/capture` | 정지 JPEG | **80** | 동작 |
| `/control` | 해상도·화질 제어 (앱이 자동 전송) | **80** | 코드엔 등록, **404 미해결** |

> - **포트 구조:** 스트림 서버 = `81`, 제어/상태 서버 = `80`. 앱은 스트림을
>   81번, `/status`·`/control`·`/capture`를 80번으로 나눠 접속합니다.
> - **fps 참고:** 지금 두 보드 모두 카메라 캡처 속도가 `약 0.3~2 fps` 로
>   매우 느린 상태입니다(큐피지가 아니라 캡처 자체, 하드웨어/드라이버급 원인
>   조사 중). 수신부(앱) 문제는 아닙니다. 이 부분은 별도 진행 중입니다.

---

## 프로젝트 구조

```
ESP32CAM_CameraWebServer/
├─ CameraWebServer/
│  ├─ CameraWebServer.ino   (메인: WiFi + 카메라 초기화)
│  ├─ wifi_config.h         ★ WiFi/보드별 IP 설정 (양쪽 보드 구분)
│  ├─ board_config.h        (카메라 모델: AI_THINKER)
│  ├─ app_httpd.cpp         (웹서버: /stream /status /control /capture)
│  ├─ camera_pins.h         (핀 맵)
│  ├─ camera_index.h        (브라우저 UI)
│  └─ partitions.csv
└─ flash.bat                (컴파일 + esptool 115200 자동 업로드)
```

---

## 준비물

- ESP32-CAM 1대 (한 번에 한 대씩)
- USB-TTL(CH340) 어댑터 1개 **또는** 기존의 ESP32-CAM 전용 프로그래머 보드 (CH340 내장)
- 점퍼 케이블 (전용 프로그래머 보드를 쓰면 **필요 없음**)
- PC 와 ESP32-CAM을 같은 WiFi(`ros5G`)에 연결해 둘 것

> 전용 프로그래머 보드(검은 캐리어)가 있으면 ESP32-CAM을 그냥 밀어 넣고
> USB만 연결하면 됩니다 — 점퍼 배선은 그 보드가 없을 때만 필요.

### 배선 (USB-TTL ↔ ESP32-CAM)  — 점퍼를 쓸 때만

| USB-TTL(CH340) | ESP32-CAM |
|---|---|
| 5V | 5V |
| GND | GND |
| TX | U0R (RX) |
| RX | U0T (TX) |

> ESP32-CAM은 5V 파워가 필요(촬영 시 5V에서 3.3V 레귤레이터 사용).
> USB-TTL의 3.3V만 쓰면 부팅 불안정.

---

## 부팅모드 (IO0 + RESET)

전용 프로그래머 보드(CH340 캐리어)는 **DTR/RTS 자동 리셋**이 되어 있어
`flash.bat`(esptool)이 알아서 부팅모드로 전환합니다 — **버튼 불필요**.

USB-TTL 점퍼 배선을 쓸 때만 아래 순서를 해 줍니다.

1. **IO0** 를 누른다 (보드 위 GPIO0 버튼)
2. IO0 누른 상태에서 **RESET** 을 살짝 눌렀다 뗀다
3. RESET 후 **IO0 를 뗀다** → 업로드 대기 상태
4. 업로드가 끝나면 RESET 한 번 눌러 정상 부팅

### 업로드 속도 (중요)

esptool 기본 460800baud 로는 이 보드에서
`Unable to verify flash chip connection` 오류가 납니다.
**115200 baud**로 쓰면 자동으로 성공합니다. (`flash.bat`이 115200 사용)

---

## 방법 A) 배치 파일로 업로드 (권장)

더블클릭: **`flash.bat`**

1. LEFT 보드를 PC에 연결 (전용 프로그래머 보드는 그냥 꽂으면 됨)
2. `flash.bat` 실행 → COM 포트 입력 (CH340 = COM25/COM26 중 장치관리자에서 확인)
3. 컴파일 + esptool 115200 업로드 자동 진행 → **[OK]** 확인 (약 70초)
4. **RIGHT** 보드로 교체
5. `CameraWebServer\wifi_config.h` 열어서 아래를
   ```
   #define AR_GLASS_BOARD  0   →   #define AR_GLASS_BOARD  1
   ```
   로 바꿔 저장
6. RIGHT 보드를 연결하고 `flash.bat` 다시 실행

> `arduino-cli` 는 Arduino IDE 2.x 기본 설치 경로를 자동 사용합니다.
> IDE 2.x가 없으면 방법 B로.

---

## 방법 B) Arduino IDE (GUI)

1. **Arduino IDE 2.x** 설치 (기본 경로)
2. 파일 → 환경설정 → 추가 보드 매니저 URL에
   `https://espressif.github.io/arduino-esp32/package_esp32_index.json` 추가
3. 보드 매니저에서 **esp32 by Espressif** 설치 (v3.x)
4. 이 프로젝트의 `CameraWebServer\CameraWebServer.ino` 더블클릭
5. 도구:
   - 보드: **AI Thinker ESP32-CAM** (없으면 ESP32 Wrover Module / ESP32 Dev Module)
   - Partition Scheme: 기본값 (3MB APP)
   - 포트: CH340 COM 선택
6. **톱니 버튼(검증)** → 컴파일 OK 확인
7. 보드 부팅모드로 만들고 **→(업로드)**
8. 끝나면 RESET 한 번

> 업로드가 `Unable to verify flash chip connection` 으로 실패하면
> 도구 → **Upload Speed 를 115200** 으로 바꾸고 다시 시도.

RIGHT 보드에서는 `wifi_config.h`의 `AR_GLASS_BOARD`를 `1`로 바꾼 뒤 다시 업로드.

---

## 업로드 후 확인

```bat
cd C:\Users\user\Desktop\AR_Glass_Robot_Control
python -m ar_glass.checkip 192.168.0.137
python -m ar_glass.checkip 192.168.0.69
```

- `[2] 펌웨어 /status OK  framesize=... quality=...` 가 나와야 합니다.
- 라이브 태그 검출:
  ```bat
  python -m ar_glass.checkip --live --save snapshots 192.168.0.137
  ```
  태그를 카메라 앞에 대면 `ID ... 500mm conf 0.9x` 형태로 감지됩니다.

### 확인 중인 이슈

- `/control`이 404를 반환합니다(등록 코드는 있음). 원인이 해결되면
  앱 시작 시 자동 해상도 전환이 가능해집니다.
- 카메라 캡처가 `~1 fps` 수준으로 느립니다(하드웨어/드라이버 조사 중).

### IP가 바뀌면?

정적 IP를 썼다면 바뀌지 않습니다 (`LEFT=192.168.0.137`, `RIGHT=192.168.0.69`).
DHCP로 두었다면(`USE_STATIC_IP 0`) 앱 설정에서 IP만 다시 입력하거나
`config\settings.json`의 `host` 값을 수정하세요.

---

## 설정 요약 (`wifi_config.h`)

| 항목 | 값 | 설명 |
|---|---|---|
| `WIFI_SSID` | `ros5G` | WiFi 이름 |
| `WIFI_PASSWORD` | `rosrosros` | WiFi 비밀번호 |
| `AR_GLASS_BOARD` | `0`(LEFT) / `1`(RIGHT) | 보드별 IP/구분 |
| `STATIC_IP_ADDRESS` | `.137` / `.69` | 보드별 고정 IP |
| `STATIC_IP_GATEWAY` | `192.168.0.1` | 라우터 게이트웨이 |
| `USE_STATIC_IP` | `1` | DHCP로 두려면 `0` |

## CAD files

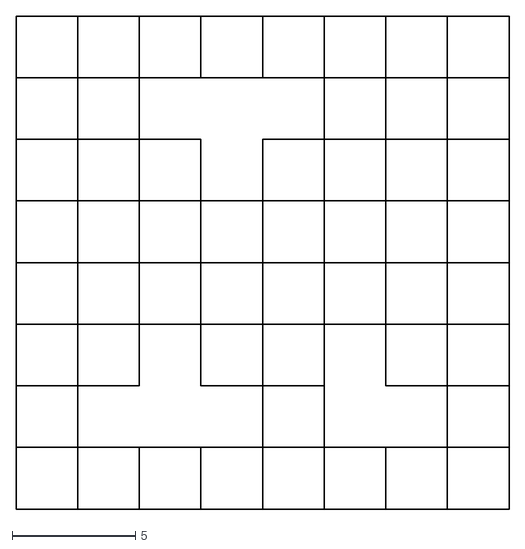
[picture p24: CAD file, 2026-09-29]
AprilTag_6개_20_0mm/ID_2_RIGHT_3_FOREARM.dxf
20.0 x 20.0

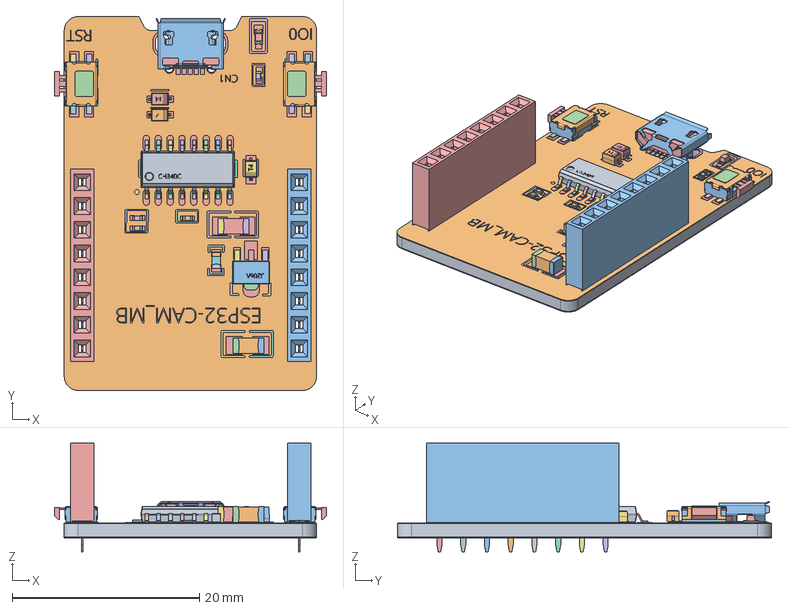
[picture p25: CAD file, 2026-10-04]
AR-Glass/ESP32-CAM-MB.FCStd
29.1 x 40.0 x 11.6 mm
Mask_up001
Mask_dwn
Plates_dwn
Plates_up
ESP32-CAM-MB001
ESP32-CAM-MB002
ESP32-CAM-MB003
ESP32-CAM-MB004
ESP32-CAM-MB005
ESP32-CAM-MB006
ESP32-CAM-MB007
ESP32-CAM-MB008
ESP32-CAM-MB009
ESP32-CAM-MB010
ESP32-CAM-MB011
ESP32-CAM-MB012
RST001
RST002
RST003
IO0
IO001
IO002
CN1
CN001
CN002
Border_001
Border_002
Border_003
Border_004
Border_005
Border_006
Border_007
Border_008
Border_009
Border_010
Border_011
Border_012
Border_013
Border_014
Border_015
Border_016
Border_017
Border_018
Border_019
Border_020
Border_021
Border_022
Case005
Pin035
Pin036
Pin037
Pin038
Pin039
Pin040
Pin041
Pin042
Pin043
Pin044
Pin045
Pin046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

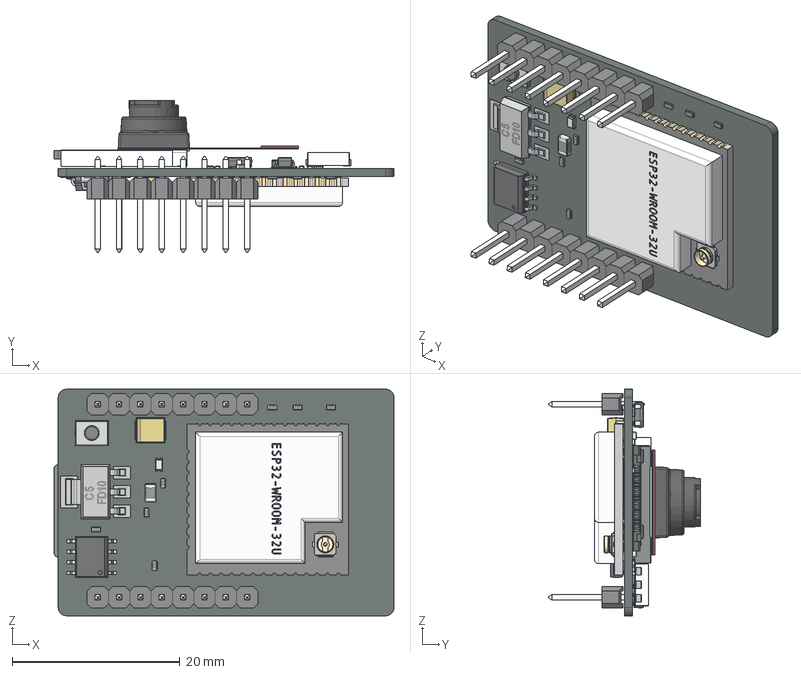
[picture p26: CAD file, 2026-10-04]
AR-Glass/esp32-cam/ESP32-cam/ESP3-CAM v5 - black pcb.step
40.5 x 18.1 x 27.0 mm
Pin Header 4 x 1 TH 2.54mm Pitch x 4
u
capacitor-CAPM-TANTB-YL
switch-3x4x2mm - 2 Pad
nano - reg
icbody
Component5(Mirror) x 4
resistor-NTC-0402-T0.6 x 20
resistor-NTC-0805-T1.3
smd-transistor-SOT23-3 x 4
LED SMD 5050 White
capacitor-CAPC-0603-T0.9-BN x 2
connector smd usl00-20l_p0-4_l12-6_w2-75
sdreader
AMS1117
Micro SD-Card
User Library-ov9655_ov9655_flex_pcb
User Library-ov9655_ov9655_flex_reinf
User Library-ov9655_ov9655_back_panel
User Library-ov9655_ov9655_body
User Library-ov9655_ov9655_lens

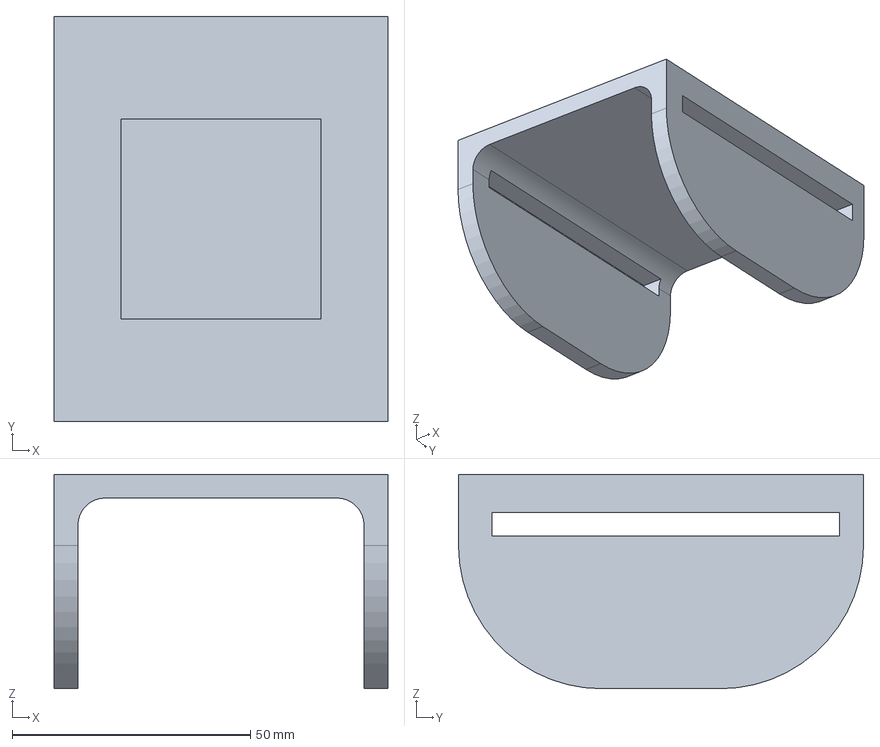
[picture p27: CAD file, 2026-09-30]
Wirst_V0.1.FCStd
70.0 x 85.0 x 45.0 mm

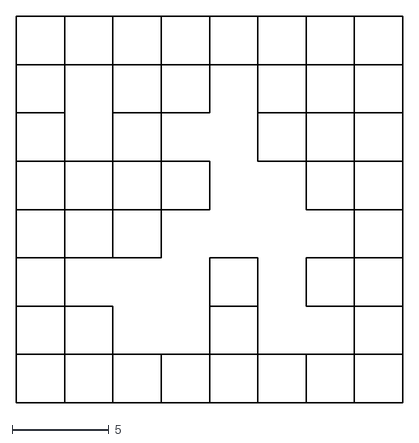
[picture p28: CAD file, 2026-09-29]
AprilTag_6개_20_0mm/ID_1_RIGHT_2_HAND.dxf
20.0 x 20.0

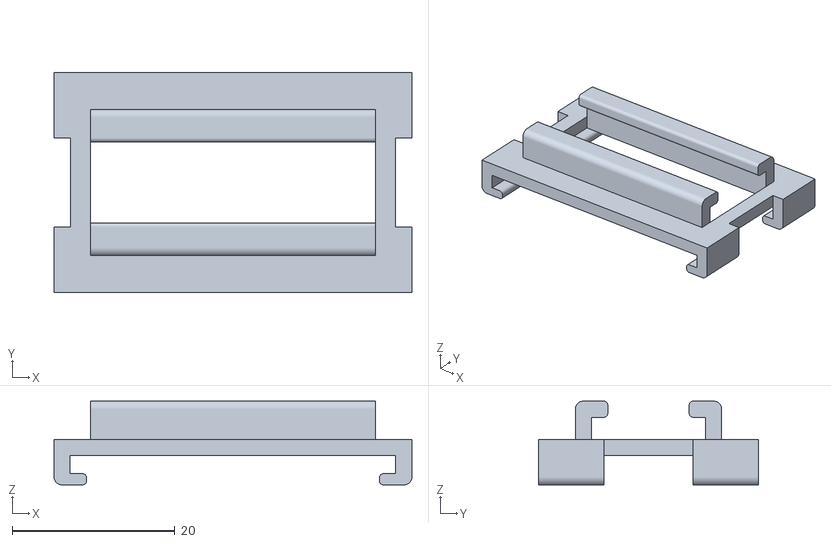
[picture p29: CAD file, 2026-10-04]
AR-Glass/Holder2.stl
44.0 x 27.0 x 10.3

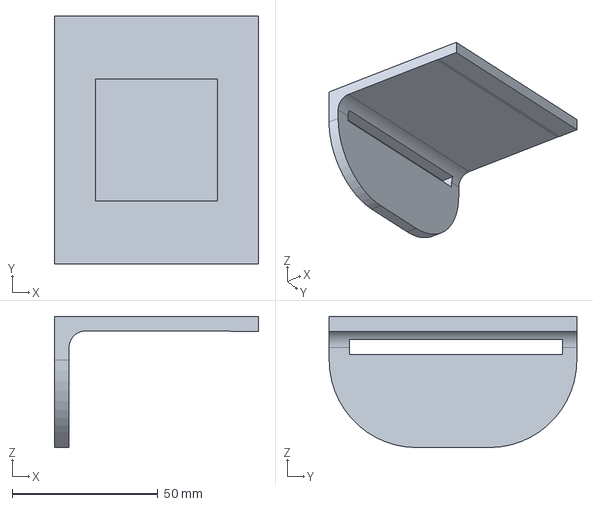
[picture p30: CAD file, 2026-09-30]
Wirst_V0.2_L.FCStd
70.0 x 85.0 x 45.0 mm

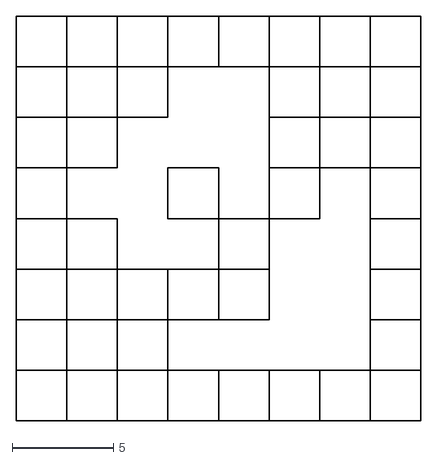
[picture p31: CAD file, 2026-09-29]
AprilTag_6개_20_0mm/ID_5_LEFT_3_FOREARM.dxf
20.0 x 20.0

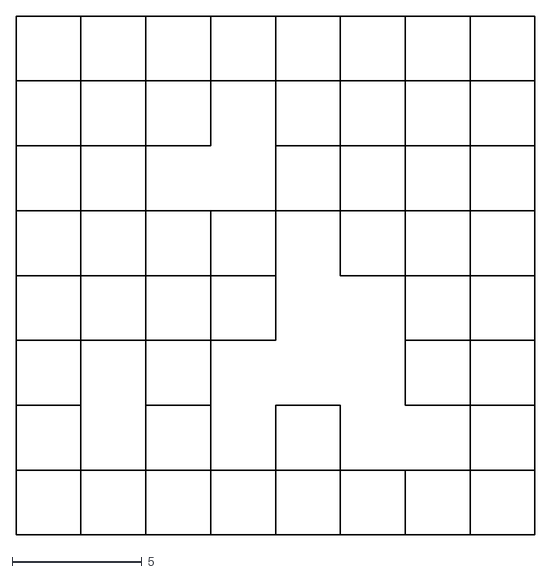
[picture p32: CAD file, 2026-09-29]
AprilTag_6개_20_0mm/ID_0_RIGHT_1_THUMB_INDEX.dxf
20.0 x 20.0

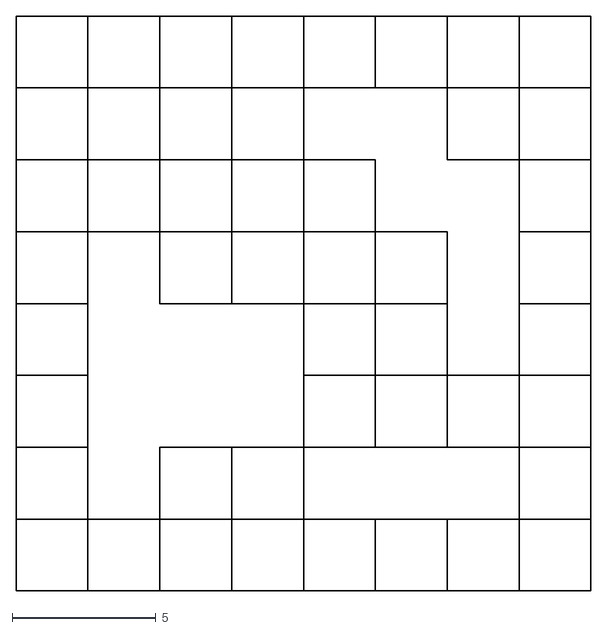
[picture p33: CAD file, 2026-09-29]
AprilTag_6개_20_0mm/ID_3_LEFT_1_THUMB_INDEX.dxf
20.0 x 20.0

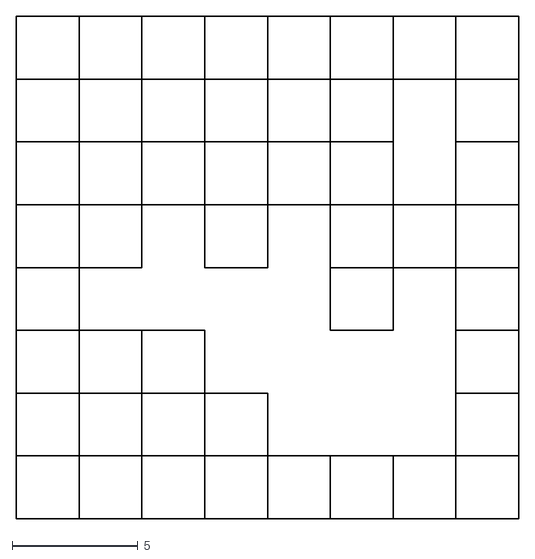
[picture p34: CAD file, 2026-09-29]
AprilTag_6개_20_0mm/ID_4_LEFT_2_HAND.dxf
20.0 x 20.0

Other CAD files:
AR-Glass/esp32-cam-mb/ESP32-CAM-MB v1.step
AR-Glass/esp32-cam/ESP32-cam/ESP3-CAM v4.step
AR-Glass/AR_GLASS.FCStd
AR-Glass/esp32-cam/ESP32-cam/ESP3-CAM v3.iges
Wirst_V0.2_R.FCStd
AR-Glass/Holder.FCStd
AR-Glass/esp32-cam.FCStd
AR-Glass/Holder.stl

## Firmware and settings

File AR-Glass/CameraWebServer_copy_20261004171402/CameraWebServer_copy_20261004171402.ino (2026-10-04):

#include <Arduino.h>
#include "esp_camera.h"
#include <WiFi.h>

// ===========================
// Select camera model in board_config.h
// ===========================
#include "board_config.h"

// ===========================
// Enter your WiFi credentials
// ===========================
const char *ssid = "NETGEAR10";
const char *password = "!Rlaskadn119";

void startCameraServer();
void setupLedFlash();

void setup() {
  Serial.begin(115200);
  Serial.setDebugOutput(true);
  Serial.println();

  camera_config_t config;
  config.ledc_channel = LEDC_CHANNEL_0;
  config.ledc_timer = LEDC_TIMER_0;
  config.pin_d0 = Y2_GPIO_NUM;
  config.pin_d1 = Y3_GPIO_NUM;
  config.pin_d2 = Y4_GPIO_NUM;
  config.pin_d3 = Y5_GPIO_NUM;
  config.pin_d4 = Y6_GPIO_NUM;
  config.pin_d5 = Y7_GPIO_NUM;
  config.pin_d6 = Y8_GPIO_NUM;
  config.pin_d7 = Y9_GPIO_NUM;
  config.pin_xclk = XCLK_GPIO_NUM;
  config.pin_pclk = PCLK_GPIO_NUM;
  config.pin_vsync = VSYNC_GPIO_NUM;
  config.pin_href = HREF_GPIO_NUM;
  config.pin_sccb_sda = SIOD_GPIO_NUM;
  config.pin_sccb_scl = SIOC_GPIO_NUM;
  config.pin_pwdn = PWDN_GPIO_NUM;
  config.pin_reset = RESET_GPIO_NUM;
  config.xclk_freq_hz = 20000000;
  config.frame_size = FRAMESIZE_UXGA;
  config.pixel_format = PIXFORMAT_JPEG;  // for streaming
  //config.pixel_format = PIXFORMAT_RGB565; // for face detection/recognition
  config.grab_mode = CAMERA_GRAB_WHEN_EMPTY;
  config.fb_location = CAMERA_FB_IN_PSRAM;
  config.jpeg_quality = 12;
  config.fb_count = 1;

  // if PSRAM IC present, init with UXGA resolution and higher JPEG quality
  //                      for larger pre-allocated frame buffer.
  if (config.pixel_format == PIXFORMAT_JPEG) {
    if (psramFound()) {
      config.jpeg_quality = 10;
      config.fb_count = 2;
      config.grab_mode = CAMERA_GRAB_LATEST;
    } else {
      // Limit the frame size when PSRAM is not available
      config.frame_size = FRAMESIZE_SVGA;
      config.fb_location = CAMERA_FB_IN_DRAM;
    }
  } else {
    // Best option for face detection/recognition
    config.frame_size = FRAMESIZE_240X240;
#if CONFIG_IDF_TARGET_ESP32S3
    config.fb_count = 2;
#endif
  }

#if defined(CAMERA_MODEL_ESP_EYE)
  pinMode(13, INPUT_PULLUP);
  pinMode(14, INPUT_PULLUP);
#endif

  // camera init
  esp_err_t err = esp_camera_init(&config);
  if (err != ESP_OK) {
    Serial.printf("Camera init failed with error 0x%x", err);
    return;
  }

  sensor_t *s = esp_camera_sensor_get();
  // initial sensors are flipped vertically and colors are a bit saturated
  if (s->id.PID == OV3660_PID) {
    s->set_vflip(s, 1);        // flip it back
    s->set_brightness(s, 1);   // up the brightness just a bit
    s->set_saturation(s, -2);  // lower the saturation
  }
  // drop down frame size for higher initial frame rate
  if (config.pixel_format == PIXFORMAT_JPEG) {
    s->set_framesize(s, FRAMESIZE_QVGA);
  }

#if defined(CAMERA_MODEL_M5STACK_WIDE) || defined(CAMERA_MODEL_M5STACK_ESP32CAM)
  s->set_vflip(s, 1);
  s->set_hmirror(s, 1);
#endif

#if defined(CAMERA_MODEL_ESP32S3_EYE)
  s->set_vflip(s, 1);
#endif

// Setup LED FLash if LED pin is defined in camera_pins.h
#if defined(LED_GPIO_NUM)
  setupLedFlash();
#endif

  WiFi.begin(ssid, password);
  WiFi.setSleep(false);

  Serial.print("WiFi connecting");
  while (WiFi.status() != WL_CONNECTED) {
    delay(500);
    Serial.print(".");
  }
  Serial.println("");
  Serial.println("WiFi connected");

  startCameraServer();

  Serial.print("Camera Ready! Use 'http://");
  Serial.print(WiFi.localIP());
  Serial.println("' to connect");
}

void loop() {
  // Do nothing. Everything is done in another task by the web server
  delay(10000);
}

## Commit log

2026-10-04 Update README with new camera and glass images
    Added additional camera images and glass images to the README.
2026-10-04 Auto-sync: 2026-10-04 20:57:30
    [AR_GLASS.FCStd, ESP3-CAM v3.iges, ESP3-CAM v4.step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]
